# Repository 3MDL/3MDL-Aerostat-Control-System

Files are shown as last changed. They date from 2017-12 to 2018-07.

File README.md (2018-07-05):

# Aerostat Control System #
Remote control system of Tetracam RGB+3 Multispectral camera
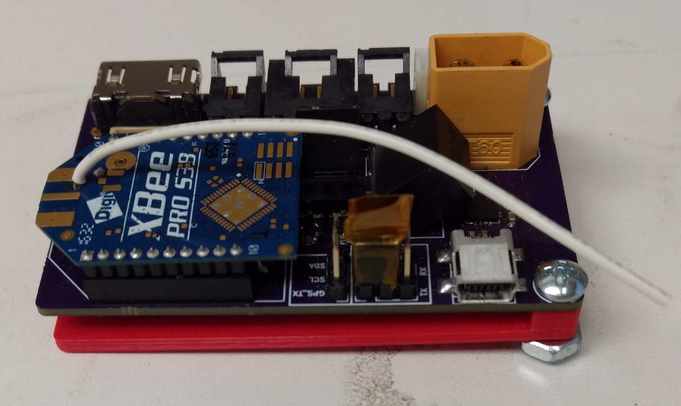
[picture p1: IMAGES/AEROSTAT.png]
image goes here

## Funcions currently implemented ##
- GPS parsing
- Timer based picture taking with settings via EEPROM
- General control over power of attached devices
- RGB+3 diagnostic mode auto-exit

## Functions needed to be implemented ##
- Low battery cuttoff
- Power modes?
- GPS power control on timer like camera

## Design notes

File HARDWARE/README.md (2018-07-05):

# Hardware Docs #

## Load Switch Modules ##
- Utilize the Fairchild FPF2701MX load switch
- Include current shunt resistor and current set resistor

## Voltage Regulator Modules ##
- Stability issues on REV A
- Stability issues on REV B
- Currently using Recom R-78 Module

## Main Board REV C ##
- Redesign that ditches the Pi and instead only uses the ATMega328P
- Uses new Recom R-78 buck regulator module

## Main Board REV D ##
- Fixes numerous pinout issues with REV C
- Passive components moved to bottom side to aid layout
- New connectors are used that utilize side entry to compact the system further

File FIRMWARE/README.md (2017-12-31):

# Firmware Docs #

## Power Test ##
- Simple test that used an Arduino board to monitor the power draw of the RGB+3 camera

## i2c_slave ##
- Arduino sketch of the code that ran on REV A and REV B of the control board
- Includes code that interfaced the Pi with the AVR over I2C

## MAIN ##
- Main code that runs on REV C of the board

## OPTIBOOT FLASH ##
- Avrdude commands and hex file for flashing bootloader onto the ATMega328P without using the Arduino IDE

## PYTHON_PI ##
- Old code from when the project plan included transfering images to the ground using the XBee and Raspberry Pi

## Range Test, RANGE TEST 2, Range Test Desktop ##
- Multiple python scripts and output data from range tests

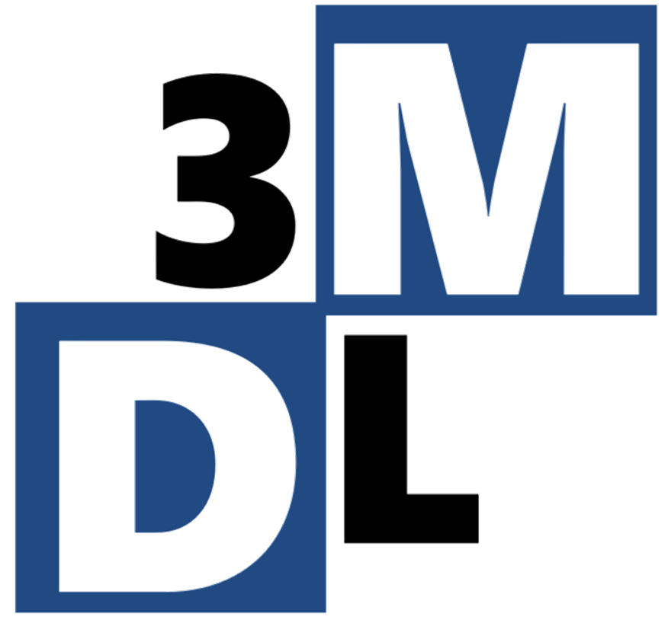
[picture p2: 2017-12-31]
HARDWARE/MOD/3MDL.bmp

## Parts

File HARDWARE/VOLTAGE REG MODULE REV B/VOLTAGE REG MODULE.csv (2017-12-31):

Id | Designator | Package | Quantity | Designation | Supplier and ref
1 | C1,C3 | c_elec_6.3x5.8 | 2 | 10uF
2 | C2 | C_0603 | 1 | 0.1uF
3 | L1 | C_1210 | 1 | 470uH
4 | U1 | QFN-16-1EP_3x3mm_Pitch0.5mm | 1 | TS30011-M050QFNR
5 | T1,T2,T3 | CPAD | 3 | TEST_1P

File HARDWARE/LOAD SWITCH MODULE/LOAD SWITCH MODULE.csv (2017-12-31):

Id | Designator | Package | Quantity | Designation | Supplier and ref
1 | C1,C2 | C_0805 | 2 | 10uF
2 | R1 | R_0805 | 1 | 0.01
3 | R2 | R_0603 | 1 | R
4 | T1,T2,T3,T4 | CPAD | 4 | TEST_1P
5 | U1 | DFN-8-1EP_3x3mm_Pitch0.65mm | 1 | FPF2701MPX

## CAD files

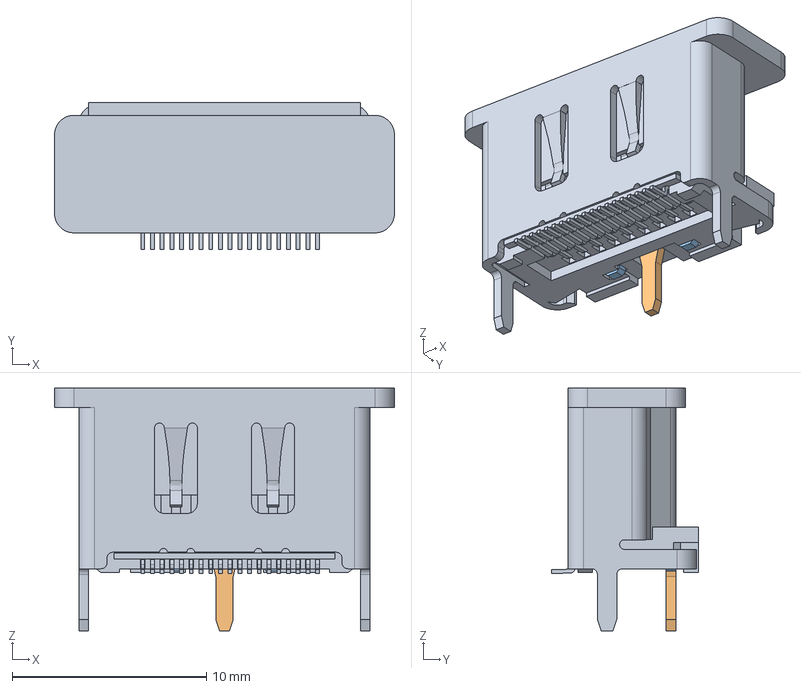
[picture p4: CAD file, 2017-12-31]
HARDWARE/WRL/476591002.stp
17.5 x 7.54 x 12.5 mm

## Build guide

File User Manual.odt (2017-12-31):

Aerostat Control System

User Manual

Table of Contents

About

Hardware Overview

Firmware Overview

Setup

Notices

Hardware Overview

Components Overview

The system consists of <number> parts. This parts include:

The main board itself

<image>

RGB+3 Camera

<image>

FPV Transmitter

<image>

FPV Receiver

<image>

XBee USB Dongle

<image>

Components Description

Main Board

The main board consists of a Printed Circuit Board (PCB) that was designed using KiCAD EDA. PCBs were ordered through OSH Park and hand assembled.

The board is designed to allow wireless control of the Tetracam RGB+3 Camera (discussed in next section). The board includes circuitry and components that utilize an XBee 900MHz Radio Module operating in pass through mode that connects to an ATMega328P (AVR) Microcontroller (MCU). The AVR runs a modified Arduino bootloader that normally runs on the Sparkfun Pro Mini 8MHz model development board. The Optiboot bootloader allows the AVR to be programmed over USB through an FTDI FT230X USB to UART serial bridge. This function is identical to most Arduino boards that do not have native USB functionality on the MCU itself. The AVR also communicates with the on board XBee module over UART serial. Since the AVR only has one hardware UART serial port, on REV C of the board, jumpers wire included to allow selecting between connecting the AVR to the FT230X bridge or the XBee module. This allows the AVR to use hardware UART serial to communicate where it matters. In REV D of the board, a multiplexer (MUX) is used to switch between connecting to the XBee and the FT230X bridge. The control signal for the MUX is the +5VDC line on the USB connector. Therefore as long as the board is plugged into a PC over USB, the board will connect the AVR to the FT230X bridge automatically.

In REV C of the main board, the GP-735T GPS module connected to the AVR using the Arduino Software Serial library. This allows the AVR to know its geographic position. The GPS also connects to the RGB+3 Camera. REV C did not include the necessary UART To RS232 Adapter that the RGB+3 requires. As a result of this, an external adapter was spliced into the system to make due. REV D (in progress) does include the adapter on the board itself to allow for a more compact system. The adapter used is the Maxim Semiconductor MAX3232 which runs off the logic level (+3.3VDC) of the rest of the board but is able of generating the larger voltage swings required for RS232 communication.

Input voltage from USB is +5VDC and is regulated to +3.3VDC using the Recom R-78 buck regulator module (+3.3VDC, 500mA). Previously (REV A & REV B) used a self designed voltage regulator module that utilized the Semtech TS30011 buck regulator. Stability issues on both designs of the regulator module. Both regulators are highly efficient buck regulators. The current Recom R-78 is a through hole module that allows use of a common linear +3.3VDC regulator such as the ST Microelectronics LD1117V33 if the Recom R-78 module is to fail or not work appropriately.

REV C included over voltage protection circuitry using a crowbar type configuration. This was because of the failed design of the voltage regulator modules. The crowbar circuits were arranged on the input 3 Cell 11.1V Lithium Polymer Battery (3S LIPO) into the board and the output of the 3.3V regulator module. On REV C, the crowbar circuits were tested to be working but since the triacs in the circuit were removable, the circuits were ran without the crowbars operation for some time. No ill effects were observed so for the sake of simplicity, the crowbar circuits were removed in REV D.

Please refer to the schematics for further information on the main board.

RGB+3 Camera

The Tetracam RGB+3 Camera is a multi spectral camera designed for use on aircraft. The camera interfaces with the main board over a standard HDMI cable. This cable can further be referred to as the Multi-GPO (General Purpose Input Output) cable. Tetracam set forth standard connections for the system. Most of these connections are standard inputs or outputs at a +3.3VDC logic level with the exception of the RS232 port that connects to the GPS. Additionally, the camera includes NTSC video over the HDMI connector as well. Beware, the HDMI does not have a standard HDMI pinout! Connecting the camera to another device over the HDMI cable is not recommended! The main board mentioned above includes the necessary connections to an First Person View (FPV) transmitter and GPS module with RS232 level shifter. The RS323 port is accessible additionally through a 3.5mm auxiallaty jack on the camera. The NTSC video stream is accessible additionally through an RCA plug on the camera.

Tetracam supplied a key shaped PCB that has a HDMI connector on one end and breakouts the different signals of the HDMI cable.

Please refer to the RGB+3 User Guide from Tetracam for more information on the camera.

FPV Transmitter

For simplicity’s sake, an external FPV transmitter was utilized, the FPV transmitter model number is the TS832 module. This module supports multiple different modules and is interfaced via a 5 pin connector.

FPV Receiver

The matching receiver for the chosen transmitter is the one included in this project. The chosen receiver’s model number is the RC832 module. This module also supports the same channels as the FPV transmitter. Normally, the FPV receiver outputs video onto an RCA type plug but this receiver was modified to include a USB video capture card. This means that the receiver can be directly plugged into a PC over USB type A in which the device acts as a standard web cam. The device is also powered over the +5VDC from the USB cable. On Debian Linux, the camera is recognized however on Windows, drivers may need to be installed. In this case, the drivers required are the USBTV007 driver.

XBee USB Dongle

The XBee USB dongle from Sparkfun allows a simple connection between the XBee and the PC. The XBees chosen are the XBee Pro 900 model with wire whip antenna. These have been tested to about 1000ft successfully. Currently the XBees are configured to run at 9600 Baud. To interface with the XBee, a COM port program needs to be installed on the host PC. For Windows, a suitable program is PuTTY. On Linux, a suitable program is CuteCom. Command processing on the main board expects to NOT see line end characters, therefore set the line ending to NONE in both programs to reliably communicate with the main board.

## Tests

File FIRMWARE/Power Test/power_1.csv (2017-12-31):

Data
0
0
0
0
0
0
0
0
0
0
0
0
0
0
0
0
0
0
0
0
0
0
0
0
0
0
0
0
0
0
0
0
0
0
0
0
0
0
0
0
0
0
0
0
0
0
0
0
0
0
0
0
0
0
0
0
0
0
0
0
0
0
0
0
0
0
0
0
0
0
0
0
0
0
0
0
0
0
0
0
0
0
0
0
0
0
0
0
0
0
0
0
0
0
0
0
0
0
0
0
0
0
0
0
0
0
0
0
0
0
0
0
0
0
0
0
0
0
0
0
0
0
0
0
0
0
0
0
0
0
0
0
0
0
0
0
0
0
0
0
0
0
0
0
0
0
0
0
0
0
0
0
0
0
0
0
0
0
0
0
0
0
0
0
0
0
0
0
0
0
0
0
0
0
0
0
0
0
0
0
0
0
0
0
0
0
0
0
0
0
0
0
0
0
0
0
0
0
0
0
0
0
0
0
0
0
0
0
0
0
0
0
0
0
0
0
0
0
0
0
0
0
0
0
0
0
0
0
0
0
0
0
0
0
0
0
0
0
0
0
0
0
0
0
0
0
0
0
0
0
0
0
0
0
0
0
0
0
0
0
0
0
0
0
0
0
0
0
0
0
0
0
0
0
0
0
0
0
0
0
0
0
0
0
0
0
0
0
0
0
0
0
0
0
0
0
0
0
0
0
0
0
0
0
0
0
0
0
0
0
0
0
0
0
0
0
0
0
0
0
0
0
0
0
0
0
0
0
0
0
0
0
0
0
0
0
0
0
0
0
0
0
0
0
0
0
0
0
0
0
0
0
0
0
0
0
0
0
0
0
0
0
0
0
0
0
0
0
0
0
0
0
0
0
0
0
0
0
0
0
0
0
0
0
0
0
0
0
0
0
0
0
0
0
0
0
0
0
0
0
0
0
0
0
0
0
0
0
0
0
0
0
0
0
0
0
0
0
0
0
0
0
0
0
0
0
0
0
0
0
0
0
0
0
0
0
0
0
0
0
0
0
0
0
0
0
0
0
0
0
0
0
0
0
0
0
0
0
0
0
0
0
0
0
0
0
0
0
0
0
0
0
0
0
0
0
0
0
0
0
0
0
0
0
0
0
0
0
0
0
0
0
0
0
0
0
0
0
0
0
0
0
0
0
0
0
0
0
0
0
0
0
0
0
0
0
0
0
0
0
0
0
0
0
0
0
0
0
0
0
0
0
0
0
0
0
0
0
0
0
0
0
0
0
0
0
0
0
0
0
0
0
0
0
0
0
0
0
0
0
0
0
0
0
0
0
0
0
0
0
0
0
0
0
0
0
0
0
0
0
0
0
0
0
0
0
0
0
0
0
0
0
0
0
0
0
0
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

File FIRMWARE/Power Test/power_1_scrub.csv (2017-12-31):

Data
0
0
0
0
0
0
0
0
0
0
0
0
0
0
0
0
0
0
0
0
0
0
0
0
0
0
0
0
0
0
0
0
0
0
0
0
0
0
0
0
0
0
0
0
0
0
0
0
0
0
0
0
0
0
0
0
0
0
0
0
0
0
0
0
0
0
0
0
0
0
0
0
0
0
0
0
0
0
0
0
0
0
0
0
0
0
0
0
0
0
0
0
0
0
0
0
0
0
0
0
0
0
0
0
0
0
0
0
0
0
0
0
0
0
0
0
0
0
0
0
0
0
0
0
0
0
0
0
0
0
0
0
0
0
0
0
0
0
0
0
0
0
0
0
0
0
0
0
0
0
0
0
0
0
0
0
0
0
0
0
0
0
0
0
0
0
0
0
0
0
0
0
0
0
0
0
0
0
0
0
0
0
0
0
0
0
0
0
0
0
0
0
0
0
0
0
0
0
0
0
0
0
0
0
0
0
0
0
0
0
0
0
0
0
0
0
0
0
0
0
0
0
0
0
0
0
0
0
0
0
0
0
0
0
0
0
0
0
0
0
0
0
0
0
0
0
0
0
0
0
0
0
0
0
0
0
0
0
0
0
0
0
0
0
0
0
0
0
0
0
0
0
0
0
0
0
0
0
0
0
0
0
0
0
0
0
0
0
0
0
0
0
0
0
0
0
0
0
0
0
0
0
0
0
0
0
0
0
0
0
0
0
0
0
0
0
0
0
0
0
0
0
0
0
0
0
0
0
0
0
0
0
0
0
0
0
0
0
0
0
0
0
0
0
0
0
0
0
0
0
0
0
0
0
0
0
0
0
0
0
0
0
0
0
0
0
0
0
0
0
0
0
0
0
0
0
0
0
0
0
0
0
0
0
0
0
0
0
0
0
0
0
0
0
0
0
0
0
0
0
0
0
0
0
0
0
0
0
0
0
0
0
0
0
0
0
0
0
0
0
0
0
0
0
0
0
0
0
0
0
0
0
0
0
0
0
0
0
0
0
0
0
0
0
0
0
0
0
0
0
0
0
0
0
0
0
0
0
0
0
0
0
0
0
0
0
0
0
0
0
0
0
0
0
0
0
0
0
0
0
0
0
0
0
0
0
0
0
0
0
0
0
0
0
0
0
0
0
0
0
0
0
0
0
0
0
0
0
0
0
0
0
0
0
0
0
0
0
0
0
0
0
0
0
0
0
0
0
0
0
0
0
0
0
0
0
0
0
0
0
0
0
0
0
0
0
0
0
0
0
0
0
0
0
0
0
0
0
0
0
0
0
0
0
0
0
0
0
0
0
0
0
0
0
0
0
0
0
0
0
0
0
0
0
0
0
0
0
0
0
0
0
0
0
0
0
0
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

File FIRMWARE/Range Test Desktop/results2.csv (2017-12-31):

no-lock
no-lock
no-lock
no-lock
no-lock
no-lock
no-lock
no-lock
no-lock
no-lock
no-lock
no-lock
no-lock
no-lock
no-lock
no-lock
no-lock
no-lock
no-lock
no-lock
no-lock
no-lock
no-lock
no-lock
no-lock
no-lock
no-lock
no-lock
no-lock
no-lock
no-lock
no-lock
no-lock
no-lock
no-lock
4139.58539 | 08336.84105
4139.59691 | 08336.84269
4139.62988 | 08336.84835
4139.65172 | 08336.85186
4139.65697 | 08336.85220
4139.66180 | 08336.85274
4139.66313 | 08336.85223
4139.66588 | 08336.85027
4139.66550 | 08336.84961
4139.66550 | 08336.84904
4139.66570 | 08336.84843
4139.66600 | 08336.84787
4139.66645 | 08336.84713
4139.66664 | 08336.84655
4139.66722 | 08336.84577
4139.66751 | 08336.84500
4139.66821 | 08336.84431
4139.66854 | 08336.84356
4139.66852 | 08336.84288
4139.66885 | 08336.84221
4139.66968 | 08336.84159
4139.66987 | 08336.84098
4139.67000 | 08336.84022
4139.67027 | 08336.83956
4139.67068 | 08336.83891
4139.67160 | 08336.83819
4139.67235 | 08336.83702
4139.67193 | 08336.83643
4139.67276 | 08336.83587
4139.67310 | 08336.83524
4139.67380 | 08336.83478
4139.68069 | 08336.81947
4139.68095 | 08336.81860
4139.68054 | 08336.81756
4139.67994 | 08336.81642
4139.67989 | 08336.81599
no-lock
no-lock
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

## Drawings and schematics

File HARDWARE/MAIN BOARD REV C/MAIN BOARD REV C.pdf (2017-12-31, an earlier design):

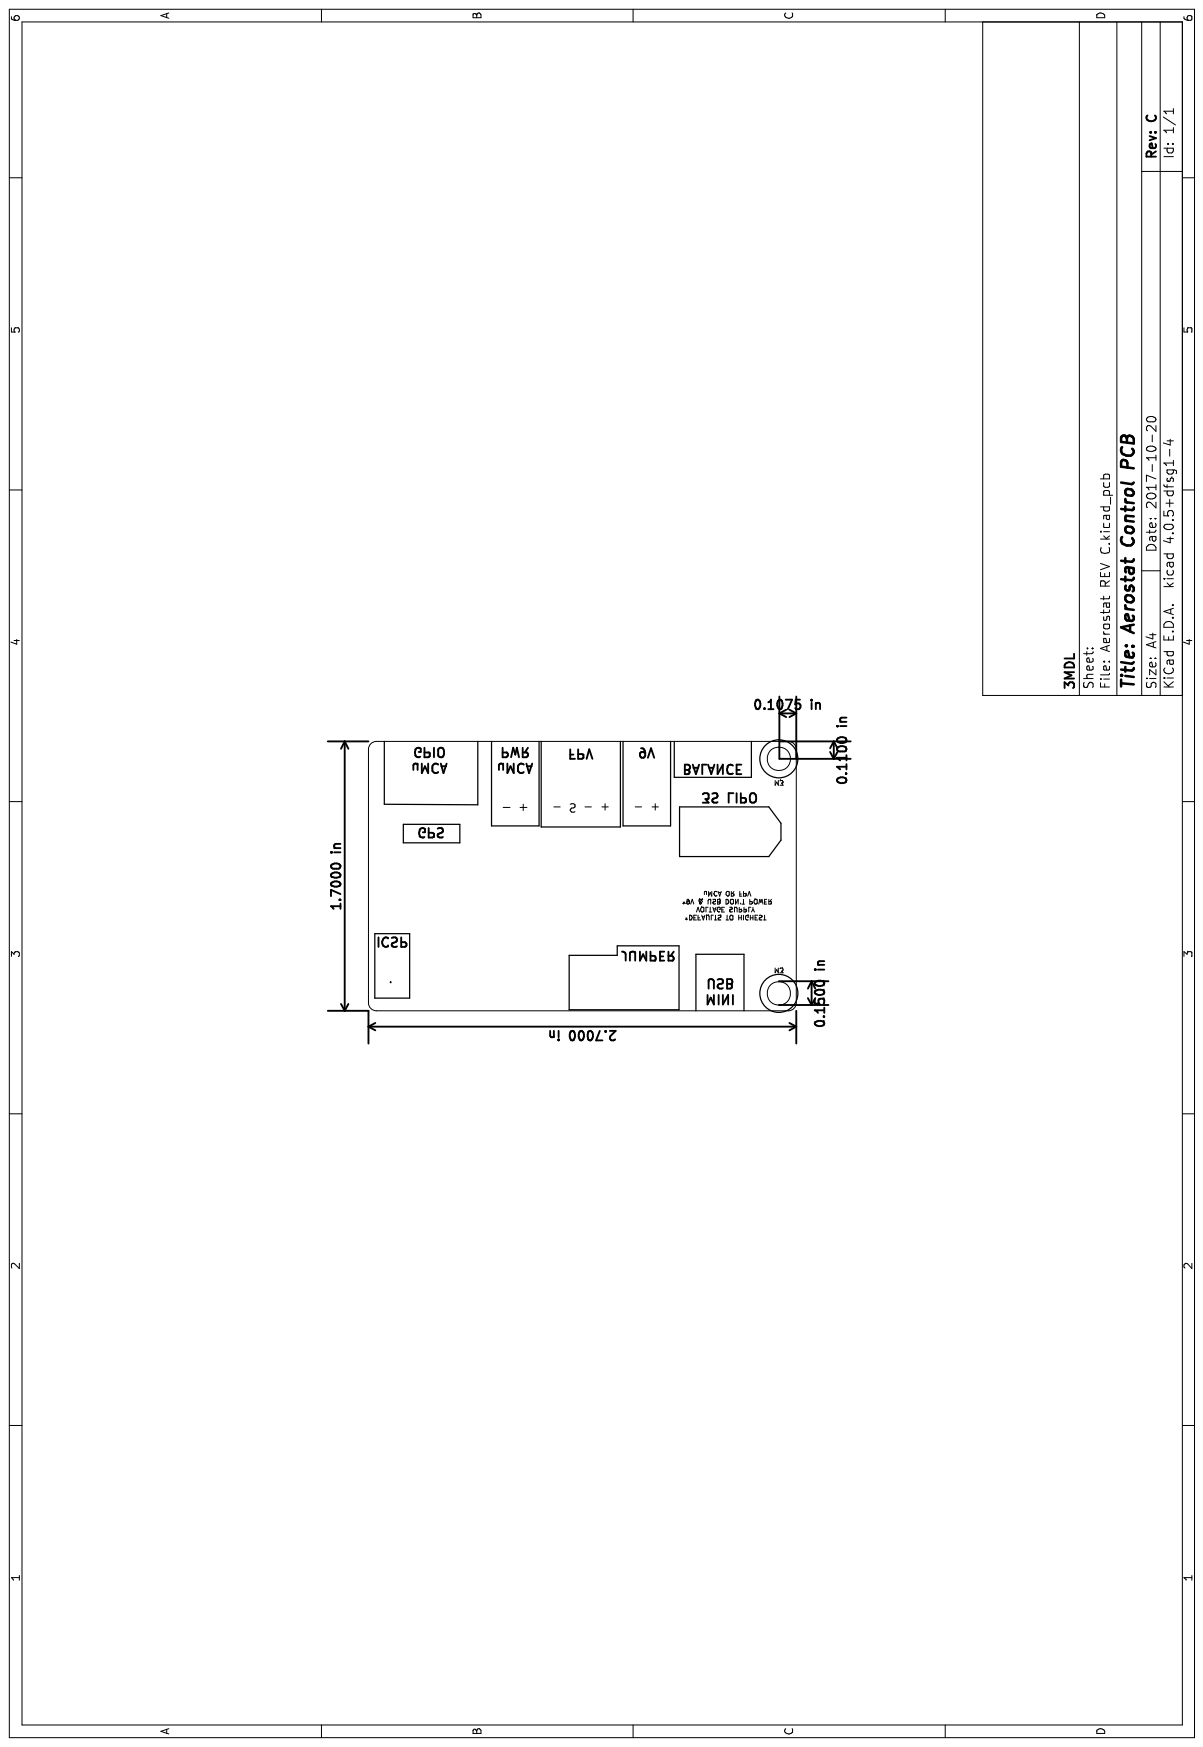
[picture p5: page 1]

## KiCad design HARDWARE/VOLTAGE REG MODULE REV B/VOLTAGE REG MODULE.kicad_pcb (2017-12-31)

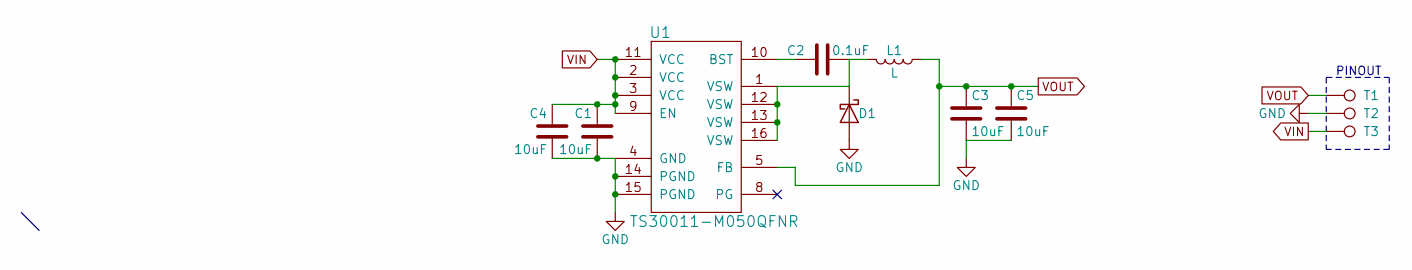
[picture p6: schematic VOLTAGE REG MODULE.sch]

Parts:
C1, C3, C4, C5: 10uF; C_0805
C2: 0.1uF; C_0603
D1: D_Schottky; SOD-123
L1: L; C_1210
T1, T2, T3: TEST_1P; CPAD
U1: TS30011-M050QFNR; QFN-16-1EP_3x3mm_Pitch0.5mm

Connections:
GND: C1.2, C3.2, C4.2, C5.2, D1.2 (A), T2.1, U1.4 (GND), U1.14 (PGND), U1.15 (PGND), U1.17
unnamed: C2.1, D1.1 (K), L1.2, U1.1 (VSW), U1.12 (VSW), U1.13 (VSW), U1.16 (VSW)
unnamed: C2.2, U1.10 (BST)
VIN: C1.1, C4.1, T3.1, U1.2 (VCC), U1.3 (VCC), U1.9 (EN), U1.11 (VCC)
VOUT: C3.1, C5.1, L1.1, T1.1, U1.5 (FB)

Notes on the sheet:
PINOUT

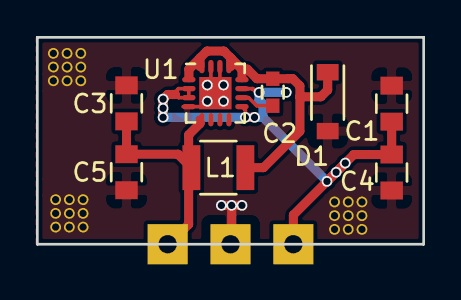
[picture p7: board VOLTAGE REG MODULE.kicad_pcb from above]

Board: 2 copper layers, 21.5 x 11.5 mm, 11 parts (0 on the bottom side), 5 nets.

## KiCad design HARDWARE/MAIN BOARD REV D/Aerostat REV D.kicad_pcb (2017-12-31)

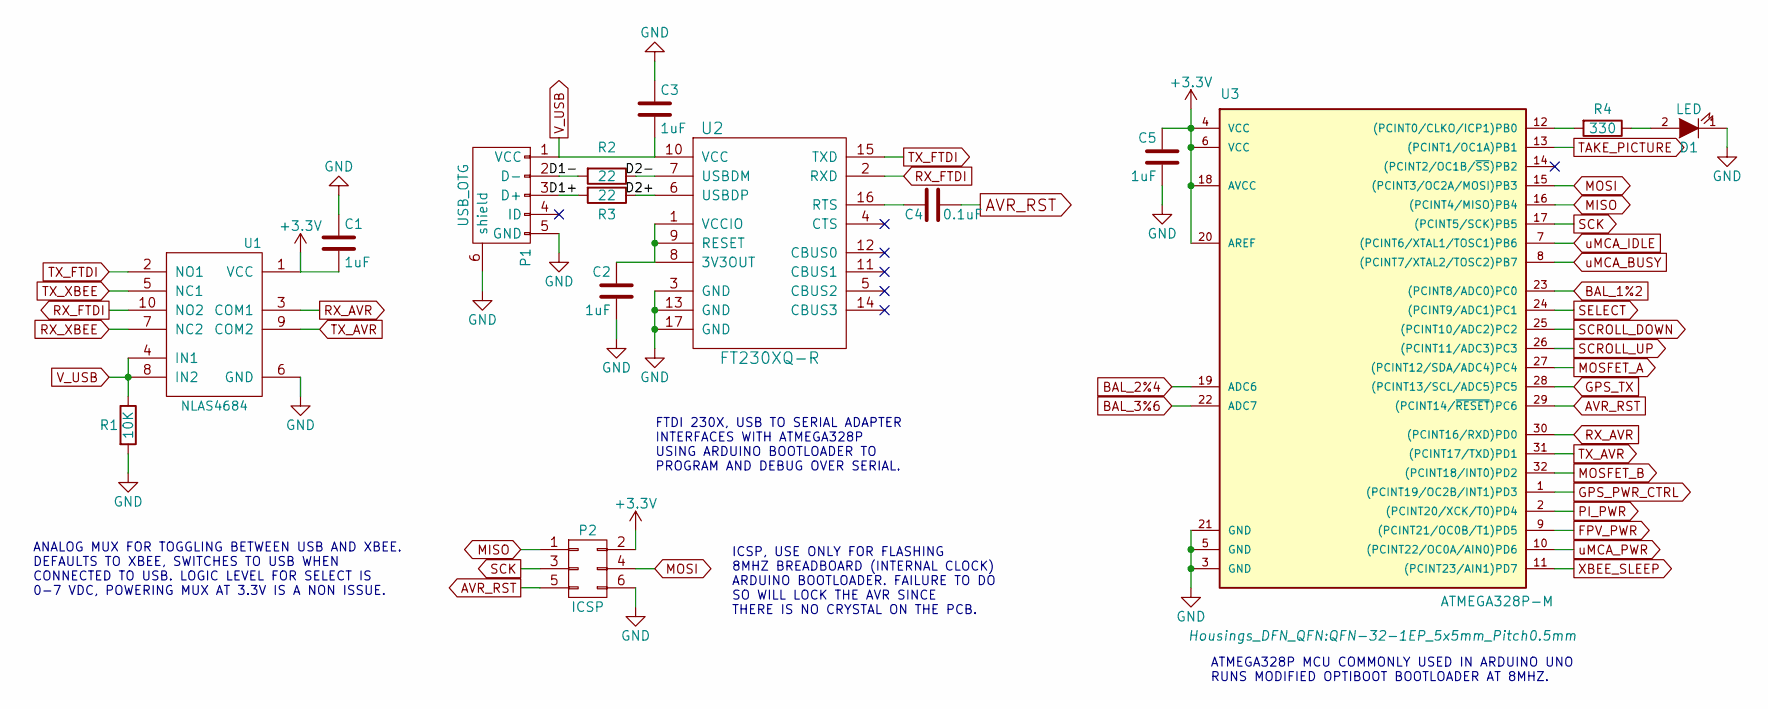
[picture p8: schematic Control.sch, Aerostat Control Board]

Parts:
C1, C2, C3, C5: 1uF; C_0603
C4: 0.1uF; C_0603
D1: LED; LED_0603
P1: USB_OTG; UX60-MB-5ST
P2: ICSP; 2.54 ICSP
R1: 10K; R_0603
R2, R3: 22; R_0603
R4: 330; R_0603
U1: NLAS4684; DFN-10-1EP_3x3mm_Pitch0.5mm
U2: FT230XQ-R; QFN-16-1EP_4x4mm_Pitch0.65mm
U3: ATMEGA328P-M; QFN-32-1EP_5x5mm_Pitch0.5mm

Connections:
+3V3: C1.2, C5.1, P2.2, U1.1 (VCC), U3.4 (VCC), U3.6 (VCC), U3.18 (AVCC), U3.20 (AREF); also elsewhere on the board
/Control/D1+: P1.3 (D+), R3.2
/Control/D1-: P1.2 (D-), R2.2
/Control/D2+: R3.1, U2.6 (USBDP)
/Control/D2-: R2.1, U2.7 (USBDM)
AVR_RST: C4.1, P2.5, U3.29 ((PCINT14/~RESET~)PC6)
BAL_1%2: U3.23 ((PCINT8/ADC0)PC0); also elsewhere on the board
BAL_2%4: U3.19 (ADC6); also elsewhere on the board
BAL_3%6: U3.22 (ADC7); also elsewhere on the board
FPV_PWR: U3.9 ((PCINT21/OC0B/T1)PD5); also elsewhere on the board
GND: C1.1, C2.2, C3.1, C5.2, D1.1 (K), P1.5 (GND), P1.6 (shield), P2.6, R1.2, U1.6 (GND), U2.3 (GND), U2.13 (GND), U2.17 (GND), U3.3 (GND), U3.5 (GND), U3.21 (GND); also elsewhere on the board
GPS_PWR_CTRL: U3.1 ((PCINT19/OC2B/INT1)PD3); also elsewhere on the board
GPS_TX: U3.28 ((PCINT13/SCL/ADC5)PC5); also elsewhere on the board
MISO: P2.1, U3.16 ((PCINT4/MISO)PB4)
MOSFET_A: U3.27 ((PCINT12/SDA/ADC4)PC4); also elsewhere on the board
MOSFET_B: U3.32 ((PCINT18/INT0)PD2); also elsewhere on the board
MOSI: P2.4, U3.15 ((PCINT3/OC2A/MOSI)PB3)
unnamed: C2.1, U2.1 (VCCIO), U2.8 (3V3OUT), U2.9 (RESET)
unnamed: C4.2, U2.16 (RTS)
unnamed: D1.2 (A), R4.1
unnamed: R4.2, U3.12 ((PCINT0/CLKO/ICP1)PB0)
PI_PWR: U3.2 ((PCINT20/XCK/T0)PD4)
RX_AVR: U1.3 (COM1), U3.30 ((PCINT16/RXD)PD0)
RX_FTDI: U1.10 (NO2), U2.2 (RXD)
RX_XBEE: U1.7 (NC2); also elsewhere on the board
SCK: P2.3, U3.17 ((PCINT5/SCK)PB5)
SCROLL_DOWN: U3.25 ((PCINT10/ADC2)PC2); also elsewhere on the board
SCROLL_UP: U3.26 ((PCINT11/ADC3)PC3); also elsewhere on the board
SELECT: U3.24 ((PCINT9/ADC1)PC1); also elsewhere on the board
TAKE_PICTURE: U3.13 ((PCINT1/OC1A)PB1); also elsewhere on the board
TX_AVR: U1.9 (COM2), U3.31 ((PCINT17/TXD)PD1)
TX_FTDI: U1.2 (NO1), U2.15 (TXD)
TX_XBEE: U1.5 (NC1); also elsewhere on the board
V_USB: C3.2, P1.1 (VCC), R1.1, U1.4 (IN1), U1.8 (IN2), U2.10 (VCC); also elsewhere on the board
XBEE_SLEEP: U3.11 ((PCINT23/AIN1)PD7); also elsewhere on the board
uMCA_BUSY: U3.8 ((PCINT7/XTAL2/TOSC2)PB7); also elsewhere on the board
uMCA_IDLE: U3.7 ((PCINT6/XTAL1/TOSC1)PB6); also elsewhere on the board
uMCA_PWR: U3.10 ((PCINT22/OC0A/AIN0)PD6); also elsewhere on the board

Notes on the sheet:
ICSP, USE ONLY FOR FLASHING 8MHZ BREADBOARD (INTERNAL CLOCK) ARDUINO BOOTLOADER. FAILURE TO DO SO WILL LOCK THE AVR SINCE THERE IS NO CRYSTAL ON THE PCB.
FTDI 230X, USB TO SERIAL ADAPTER INTERFACES WITH ATMEGA328P USING ARDUINO BOOTLOADER TO PROGRAM AND DEBUG OVER SERIAL.
ATMEGA328P MCU COMMONLY USED IN ARDUINO UNO RUNS MODIFIED OPTIBOOT BOOTLOADER AT 8MHZ.
ANALOG MUX FOR TOGGLING BETWEEN USB AND XBEE. DEFAULTS TO XBEE, SWITCHES TO USB WHEN CONNECTED TO USB. LOGIC LEVEL FOR SELECT IS 0-7 VDC, POWERING MUX AT 3.3V IS A NON ISSUE.

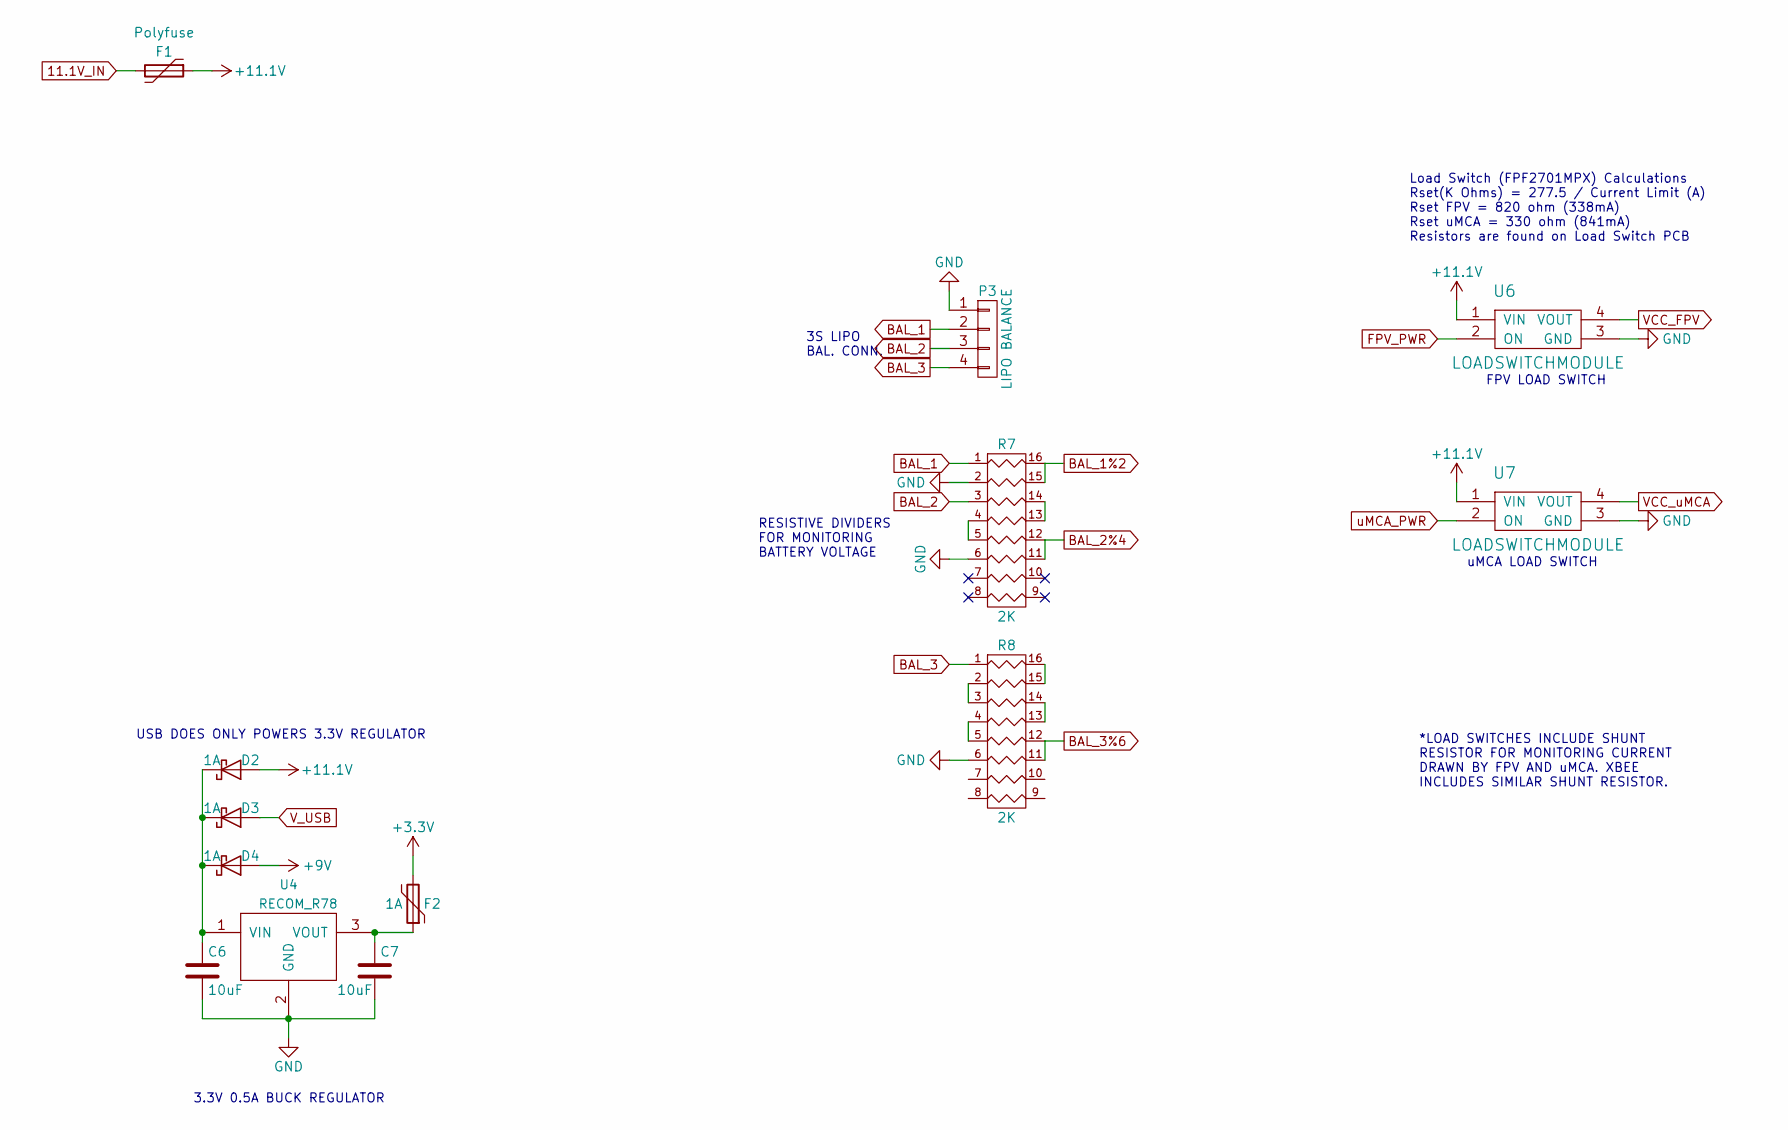
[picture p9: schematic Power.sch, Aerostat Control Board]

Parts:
C6, C7: 10uF; C_0603
D2, D3, D4: 1A; D_SOD-123
F1: Polyfuse; C_1210
F2: 1A; C_1210
P3: LIPO BALANCE; JST_B4B-XH-A(LF)(SN)
R7, R8: 2K; R_Array_Convex_8x0602
U4: RECOM_R78; R-78E
U6, U7: LOADSWITCHMODULE; LOAD SWITCH MODULE

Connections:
11.1V_IN: F1.2; also elsewhere on the board
+3V3: F2.2; also elsewhere on the board
+9V: D4.2 (A); also elsewhere on the board
+12C: D2.2 (A), F1.1, U6.1 (VIN), U7.1 (VIN)
BAL_1: P3.2, R7.1
BAL_1%2: R7.15 (R2), R7.16 (R1); also elsewhere on the board
BAL_2: P3.3, R7.3
BAL_2%4: R7.11 (R6), R7.12 (R5); also elsewhere on the board
BAL_3: P3.4, R8.1
BAL_3%6: R8.11 (R6), R8.12 (R5); also elsewhere on the board
FPV_PWR: U6.2 (ON); also elsewhere on the board
GND: C6.2, C7.2, P3.1, R7.2, R7.6, R8.6, U4.2 (GND), U6.3 (GND), U7.3 (GND); also elsewhere on the board
unnamed: C6.1, D2.1 (K), D3.1 (K), D4.1 (K), U4.1 (VIN)
unnamed: C7.1, F2.1, U4.3 (VOUT)
unnamed: R7.4, R7.5
unnamed: R7.13 (R4), R7.14 (R3)
unnamed: R8.2, R8.3
unnamed: R8.4, R8.5
unnamed: R8.13 (R4), R8.14 (R3)
unnamed: R8.15 (R2), R8.16 (R1)
VCC_FPV: U6.4 (VOUT); also elsewhere on the board
VCC_uMCA: U7.4 (VOUT); also elsewhere on the board
V_USB: D3.2 (A); also elsewhere on the board
uMCA_PWR: U7.2 (ON); also elsewhere on the board

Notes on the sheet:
3S LIPO BAL. CONN.
RESISTIVE DIVIDERS FOR MONITORING BATTERY VOLTAGE
FPV LOAD SWITCH
uMCA LOAD SWITCH
*LOAD SWITCHES INCLUDE SHUNT RESISTOR FOR MONITORING CURRENT DRAWN BY FPV AND uMCA. XBEE INCLUDES SIMILAR SHUNT RESISTOR.
Load Switch (FPF2701MPX) Calculations Rset(K Ohms) = 277.5 / Current Limit (A) Rset FPV = 820 ohm (338mA) Rset uMCA = 330 ohm (841mA) Resistors are found on Load Switch PCB
3.3V 0.5A BUCK REGULATOR
USB DOES ONLY POWERS 3.3V REGULATOR

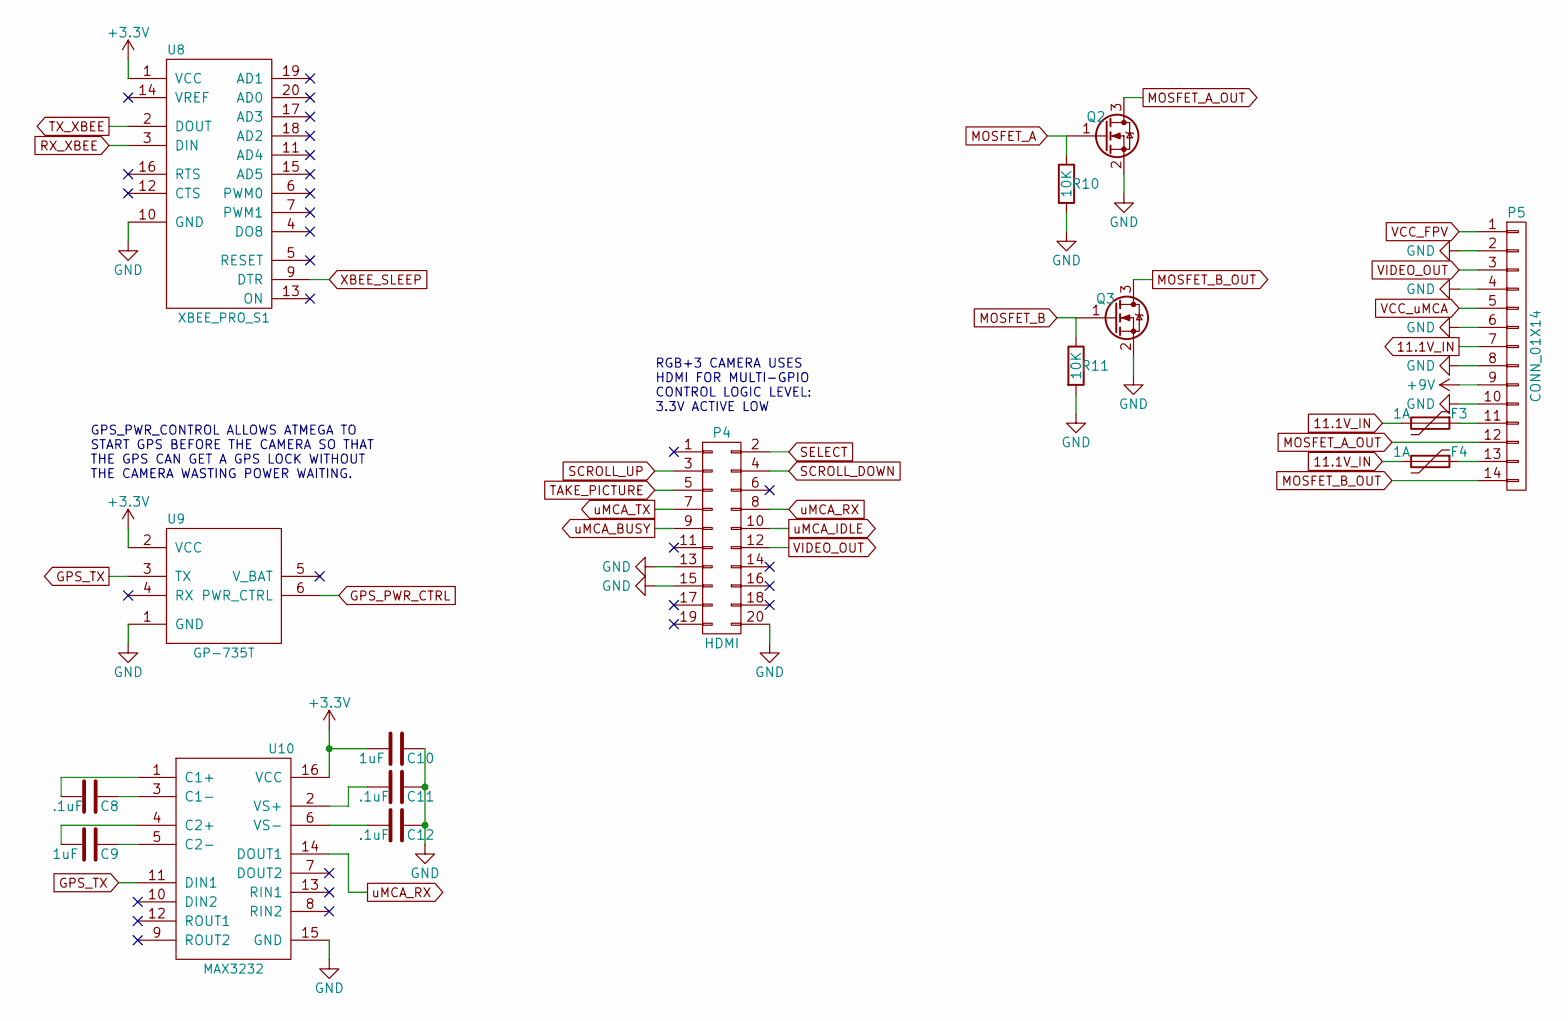
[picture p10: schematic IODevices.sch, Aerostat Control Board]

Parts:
C8, C11, C12: .1uF; C_0603
C9, C10: 1uF; C_0603
F3, F4: 1A; C_1210
P4: HDMI; 10029449-111RLF
P5: CONN_01X14; TE1X14
Q2, Q3: Q_NMOS_GSD; SOT-23
R10, R11: 10K; R_0603
U8: XBEE_PRO_S1; DIP-20
U9: GP-735T
U10: MAX3232; TSSOP-16_4.4x5mm_Pitch0.65mm

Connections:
11.1V_IN: F3.2, F4.2, P5.7; also elsewhere on the board
+3V3: C10.2, U8.1 (VCC), U9.2 (VCC), U10.16 (VCC); also elsewhere on the board
+9V: P5.9; also elsewhere on the board
GND: C10.1, C11.1, C12.1, P4.13, P4.15, P4.20, P5.2, P5.4, P5.6, P5.8, P5.10, Q2.2 (S), Q3.2 (S), R10.2, R11.2, U8.10 (GND), U9.1 (GND), U10.15 (GND); also elsewhere on the board
GPS_PWR_CTRL: U9.6 (PWR_CTRL); also elsewhere on the board
GPS_TX: U9.3 (TX), U10.11 (DIN1); also elsewhere on the board
MOSFET_A: Q2.1 (G), R10.1; also elsewhere on the board
MOSFET_A_OUT: P5.12, Q2.3 (D)
MOSFET_B: Q3.1 (G), R11.1; also elsewhere on the board
MOSFET_B_OUT: P5.14, Q3.3 (D)
unnamed: C8.1, U10.3 (C1-)
unnamed: C8.2, U10.1 (C1+)
unnamed: C9.1, U10.5 (C2-)
unnamed: C9.2, U10.4 (C2+)
unnamed: C11.2, U10.2 (VS+)
unnamed: C12.2, U10.6 (VS-)
unnamed: F3.1, P5.11
unnamed: F4.1, P5.13
RX_XBEE: U8.3 (DIN); also elsewhere on the board
SCROLL_DOWN: P4.4; also elsewhere on the board
SCROLL_UP: P4.3; also elsewhere on the board
SELECT: P4.2; also elsewhere on the board
TAKE_PICTURE: P4.5; also elsewhere on the board
TX_XBEE: U8.2 (DOUT); also elsewhere on the board
VCC_FPV: P5.1; also elsewhere on the board
VCC_uMCA: P5.5; also elsewhere on the board
VIDEO_OUT: P4.12, P5.3
XBEE_SLEEP: U8.9 (DTR); also elsewhere on the board
uMCA_BUSY: P4.9; also elsewhere on the board
uMCA_IDLE: P4.10; also elsewhere on the board
uMCA_RX: P4.8, U10.14 (DOUT1)
uMCA_TX: P4.7

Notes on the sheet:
GPS_PWR_CONTROL ALLOWS ATMEGA TO START GPS BEFORE THE CAMERA SO THAT THE GPS CAN GET A GPS LOCK WITHOUT THE CAMERA WASTING POWER WAITING.
RGB+3 CAMERA USES HDMI FOR MULTI-GPIO CONTROL LOGIC LEVEL: 3.3V ACTIVE LOW

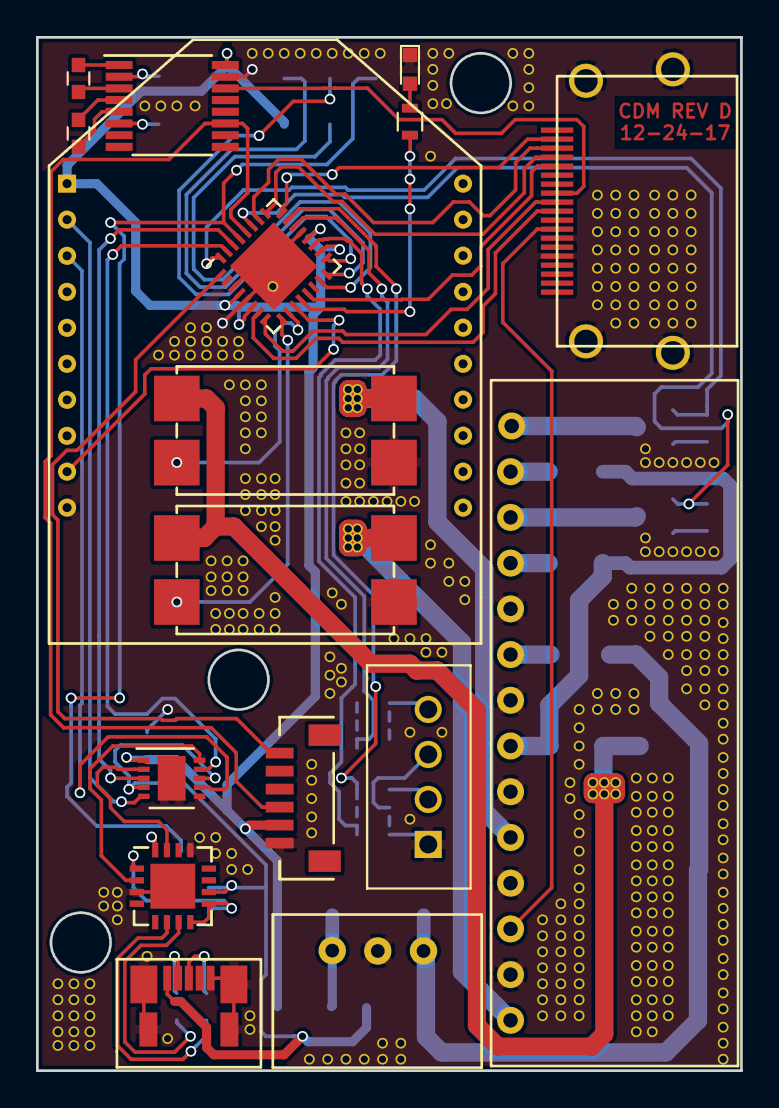
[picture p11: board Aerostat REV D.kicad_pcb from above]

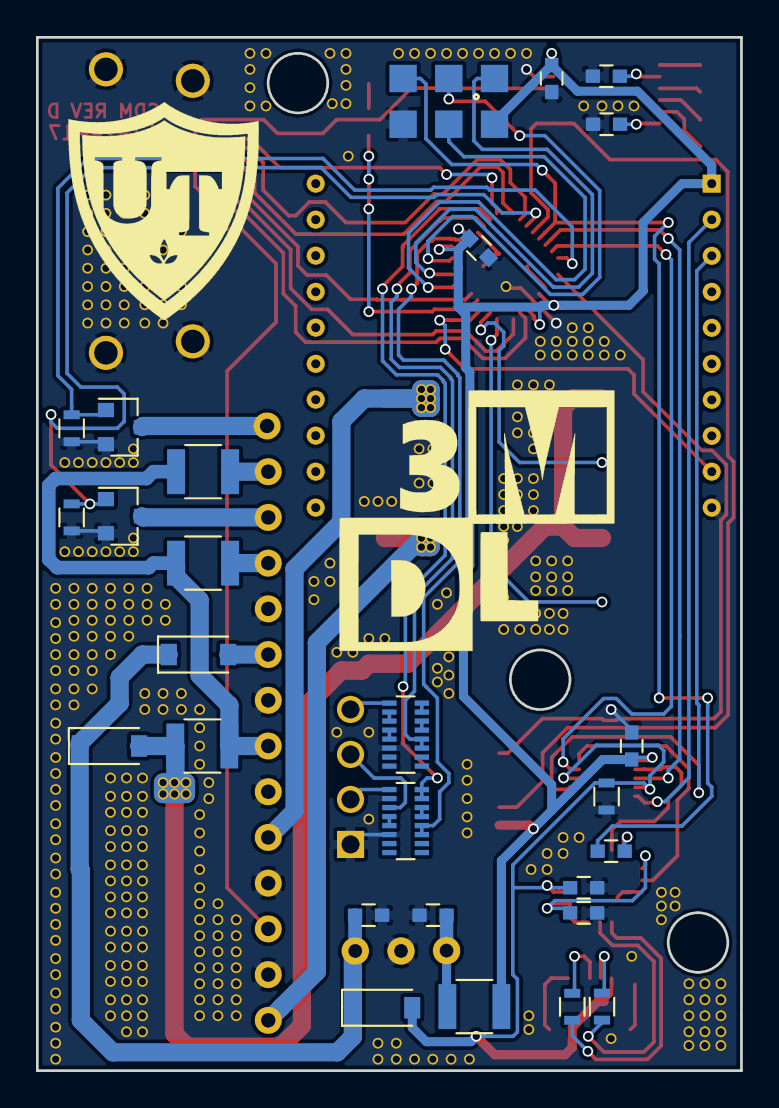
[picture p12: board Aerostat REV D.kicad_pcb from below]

Board: 2 copper layers, 39.1 x 57.4 mm, 44 parts (27 on the bottom side), 65 nets.

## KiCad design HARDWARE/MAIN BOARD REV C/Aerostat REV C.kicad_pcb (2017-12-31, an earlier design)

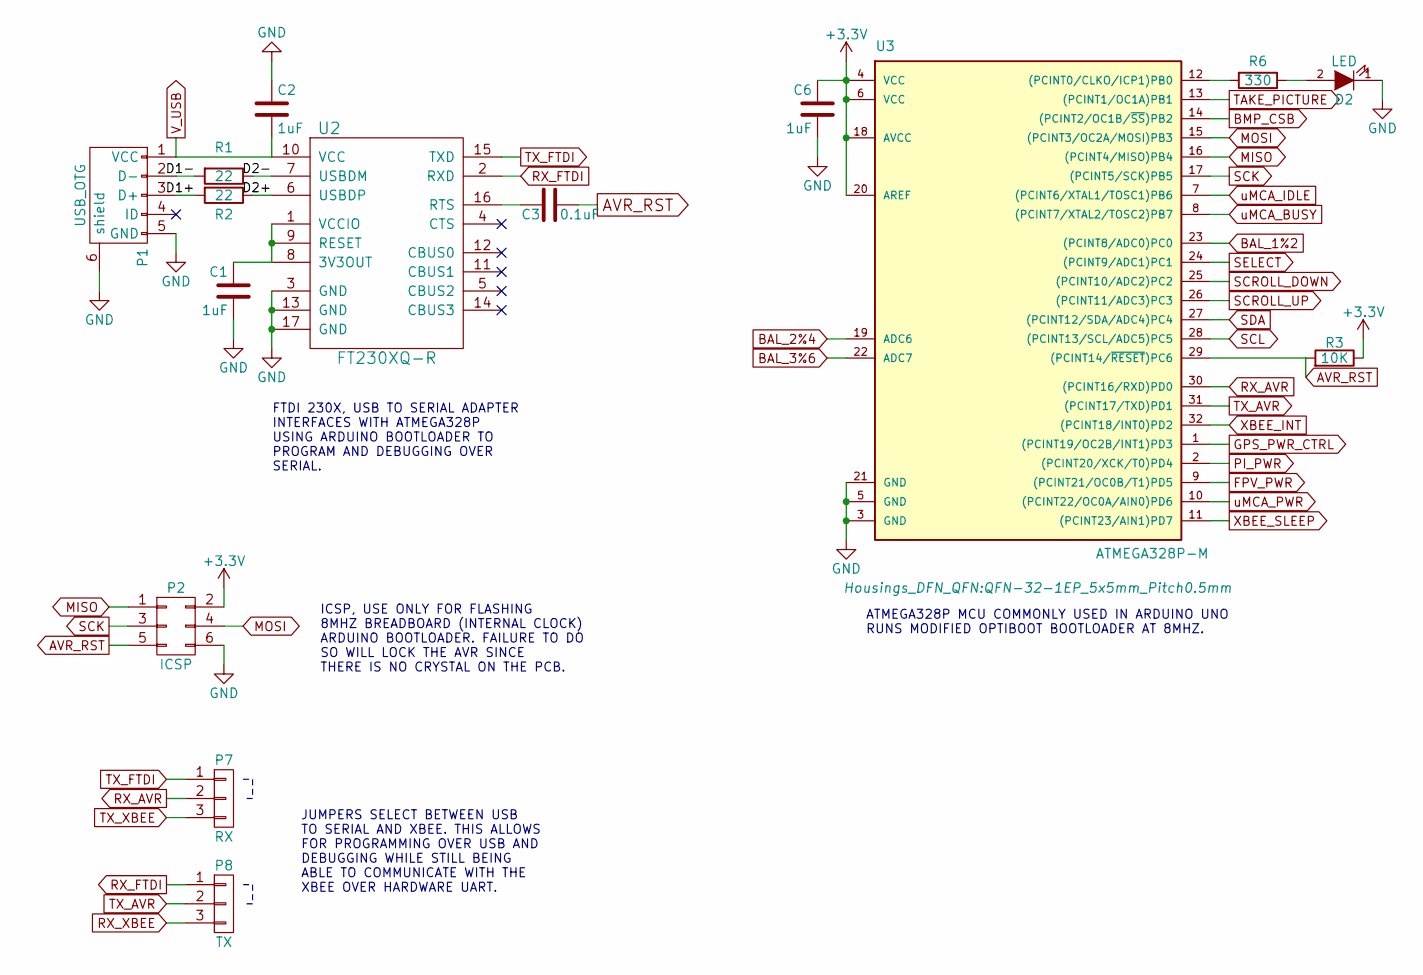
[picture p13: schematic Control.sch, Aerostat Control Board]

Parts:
C1, C2, C6: 1uF; C_0603
C3: 0.1uF; C_0603
D2: LED; LED_0603
P1: USB_OTG; UX60-MB-5ST
P2: ICSP; 2.54 ICSP
P7: RX; Pin_Header_Straight_1x03_Pitch2.54mm
P8: TX; Pin_Header_Straight_1x03_Pitch2.54mm
R1, R2: 22; R_0603
R3: 10K; R_0603
R6: 330; R_0603
U2: FT230XQ-R; QFN-16-1EP_4x4mm_Pitch0.65mm
U3: ATMEGA328P-M; QFN-32-1EP_5x5mm_Pitch0.5mm

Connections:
+3V3: C6.1, P2.2, R3.1, U3.4 (VCC), U3.6 (VCC), U3.18 (AVCC), U3.20 (AREF); also elsewhere on the board
/Control/D1+: P1.3 (D+), R2.2
/Control/D1-: P1.2 (D-), R1.2
/Control/D2+: R2.1, U2.6 (USBDP)
/Control/D2-: R1.1, U2.7 (USBDM)
AVR_RST: C3.1, P2.5, R3.2, U3.29 ((PCINT14/~RESET~)PC6)
BAL_1%2: U3.23 ((PCINT8/ADC0)PC0); also elsewhere on the board
BAL_2%4: U3.19 (ADC6); also elsewhere on the board
BAL_3%6: U3.22 (ADC7); also elsewhere on the board
BMP_CSB: U3.14 ((PCINT2/OC1B/~SS~)PB2); also elsewhere on the board
FPV_PWR: U3.9 ((PCINT21/OC0B/T1)PD5); also elsewhere on the board
GND: C1.2, C2.1, C6.2, D2.1 (K), P1.5 (GND), P1.6 (shield), P2.6, U2.3 (GND), U2.13 (GND), U2.17 (GND), U3.3 (GND), U3.5 (GND), U3.21 (GND), U3.33; also elsewhere on the board
GPS_PWR_CTRL: U3.1 ((PCINT19/OC2B/INT1)PD3); also elsewhere on the board
MISO: P2.1, U3.16 ((PCINT4/MISO)PB4); also elsewhere on the board
MOSI: P2.4, U3.15 ((PCINT3/OC2A/MOSI)PB3); also elsewhere on the board
unnamed: C1.1, U2.1 (VCCIO), U2.8 (3V3OUT), U2.9 (RESET)
unnamed: C3.2, U2.16 (RTS)
unnamed: D2.2 (A), R6.1
unnamed: R6.2, U3.12 ((PCINT0/CLKO/ICP1)PB0)
PI_PWR: U3.2 ((PCINT20/XCK/T0)PD4)
RX_AVR: P7.2, U3.30 ((PCINT16/RXD)PD0)
RX_FTDI: P8.1, U2.2 (RXD)
RX_XBEE: P8.3; also elsewhere on the board
SCK: P2.3, U3.17 ((PCINT5/SCK)PB5); also elsewhere on the board
SCL: U3.28 ((PCINT13/SCL/ADC5)PC5); also elsewhere on the board
SCROLL_DOWN: U3.25 ((PCINT10/ADC2)PC2); also elsewhere on the board
SCROLL_UP: U3.26 ((PCINT11/ADC3)PC3); also elsewhere on the board
SDA: U3.27 ((PCINT12/SDA/ADC4)PC4); also elsewhere on the board
SELECT: U3.24 ((PCINT9/ADC1)PC1); also elsewhere on the board
TAKE_PICTURE: U3.13 ((PCINT1/OC1A)PB1); also elsewhere on the board
TX_AVR: P8.2, U3.31 ((PCINT17/TXD)PD1)
TX_FTDI: P7.1, U2.15 (TXD)
TX_XBEE: P7.3; also elsewhere on the board
V_USB: C2.2, P1.1 (VCC), U2.10 (VCC); also elsewhere on the board
XBEE_INT: U3.32 ((PCINT18/INT0)PD2); also elsewhere on the board
XBEE_SLEEP: U3.11 ((PCINT23/AIN1)PD7); also elsewhere on the board
uMCA_BUSY: U3.8 ((PCINT7/XTAL2/TOSC2)PB7); also elsewhere on the board
uMCA_IDLE: U3.7 ((PCINT6/XTAL1/TOSC1)PB6); also elsewhere on the board
uMCA_PWR: U3.10 ((PCINT22/OC0A/AIN0)PD6); also elsewhere on the board

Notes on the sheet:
JUMPERS SELECT BETWEEN USB TO SERIAL AND XBEE. THIS ALLOWS FOR PROGRAMMING OVER USB AND DEBUGGING WHILE STILL BEING ABLE TO COMMUNICATE WITH THE XBEE OVER HARDWARE UART.
ICSP, USE ONLY FOR FLASHING 8MHZ BREADBOARD (INTERNAL CLOCK) ARDUINO BOOTLOADER. FAILURE TO DO SO WILL LOCK THE AVR SINCE THERE IS NO CRYSTAL ON THE PCB.
FTDI 230X, USB TO SERIAL ADAPTER INTERFACES WITH ATMEGA328P USING ARDUINO BOOTLOADER TO PROGRAM AND DEBUGGING OVER SERIAL.
ATMEGA328P MCU COMMONLY USED IN ARDUINO UNO RUNS MODIFIED OPTIBOOT BOOTLOADER AT 8MHZ.

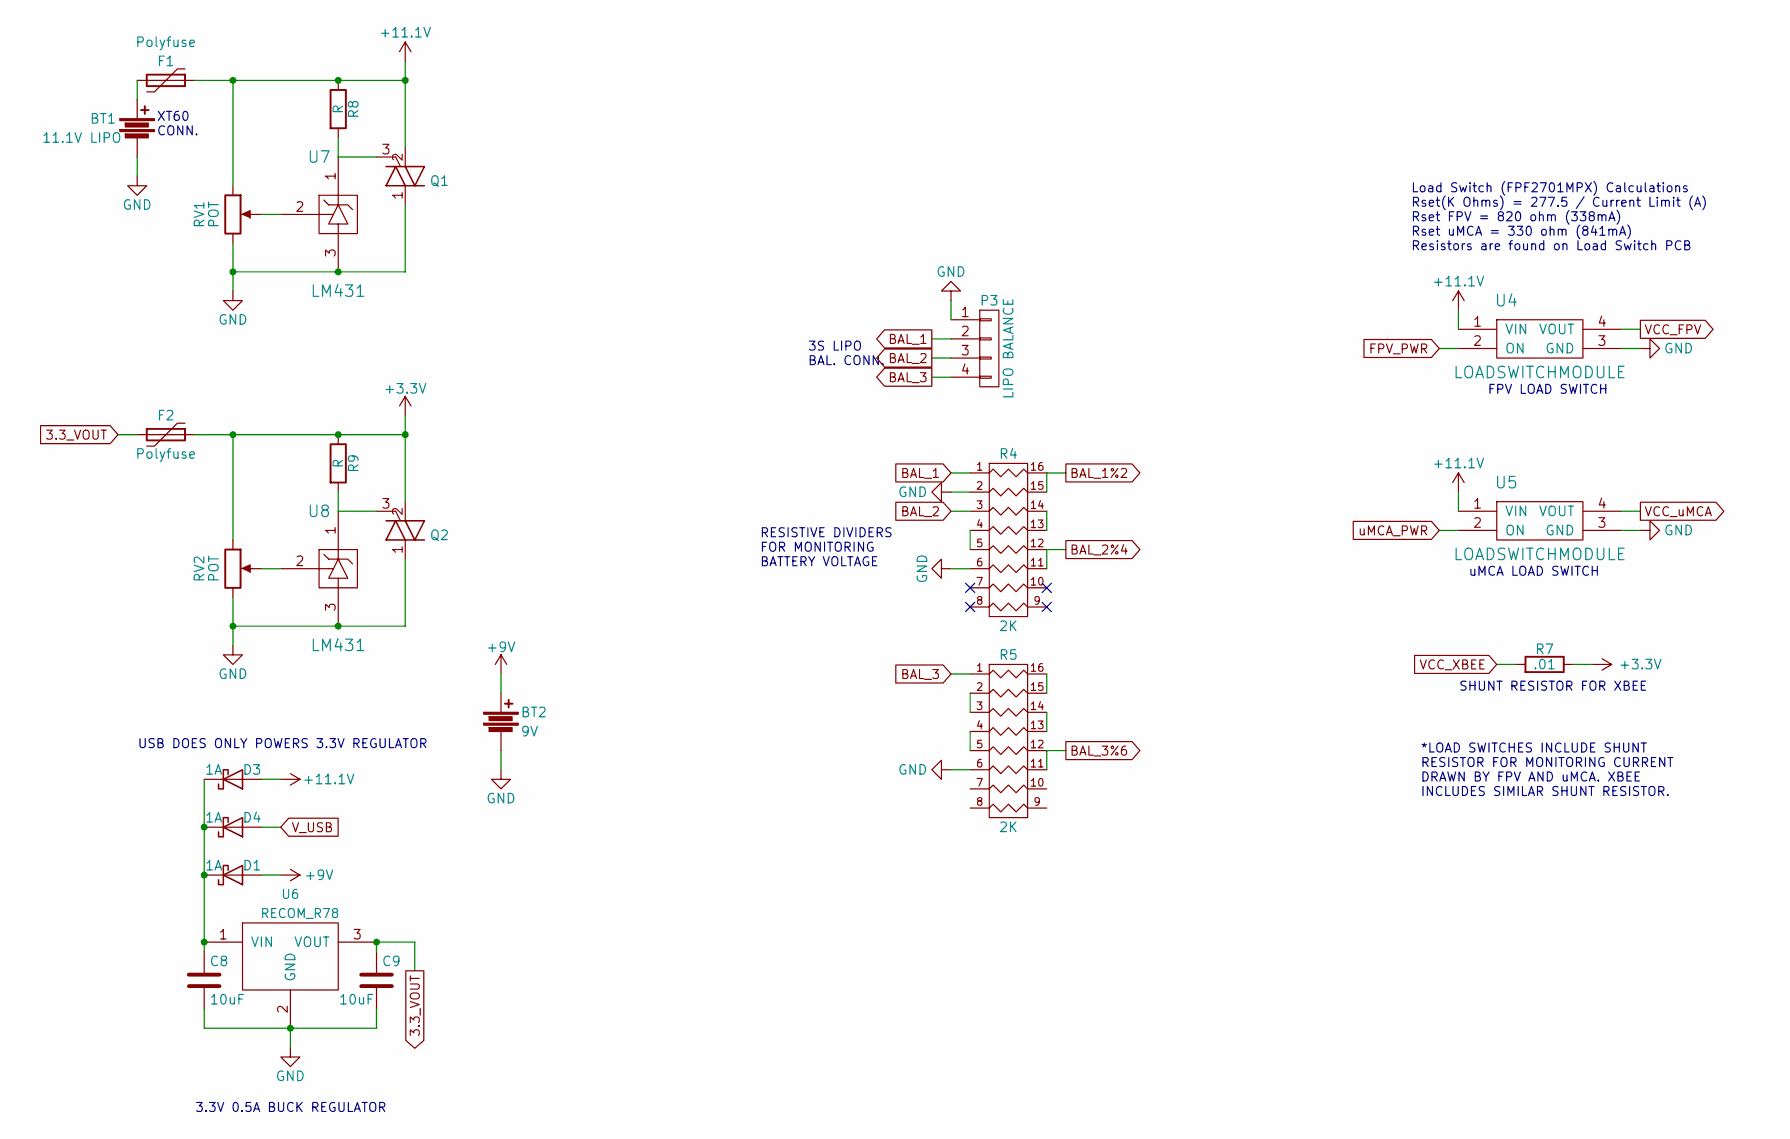
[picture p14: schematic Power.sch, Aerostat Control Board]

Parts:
BT1: 11.1V LIPO; XT60
BT2: 9V; TE1X2
C8, C9: 10uF; C_0603
D1, D3, D4: 1A; D_SOD-123
F1, F2: Polyfuse; C_1210
P3: LIPO BALANCE; JST_B4B-XH-A(LF)(SN)
Q1, Q2: Q_TRIAC_AAG; Pin_Header_Straight_1x03_Pitch2.54mm
R4, R5: 2K; R_Array_Convex_8x0602
R7: .01; R_0805
R8, R9: R; R_0603
RV1, RV2: POT; Potentiometer_Trimmer-EVM3E
U4, U5: LOADSWITCHMODULE; LOAD SWITCH MODULE
U6: RECOM_R78; R-78E
U7, U8: LM431; SOT-323_SC-70

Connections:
3.3_VOUT: C9.1, F2.2, U6.3 (VOUT)
+3V3: F2.1, Q2.2 (A2), R7.1, R9.1, RV2.1; also elsewhere on the board
+9V: BT2.1, D1.2 (A)
+12C: D3.2 (A), F1.1, Q1.2 (A2), R8.1, RV1.1, U4.1 (VIN), U5.1 (VIN)
BAL_1: P3.2, R4.1
BAL_1%2: R4.15 (R2), R4.16 (R1); also elsewhere on the board
BAL_2: P3.3, R4.3
BAL_2%4: R4.11 (R6), R4.12 (R5); also elsewhere on the board
BAL_3: P3.4, R5.1
BAL_3%6: R5.11 (R6), R5.12 (R5); also elsewhere on the board
FPV_PWR: U4.2 (ON); also elsewhere on the board
GND: BT1.2, BT2.2, C8.2, C9.2, P3.1, Q1.1 (A1), Q2.1 (A1), R4.2, R4.6, R5.6, RV1.3, RV2.3, U4.3 (GND), U5.3 (GND), U6.2 (GND), U7.3, U8.3; also elsewhere on the board
unnamed: BT1.1, F1.2
unnamed: C8.1, D1.1 (K), D3.1 (K), D4.1 (K), U6.1 (VIN)
unnamed: Q1.3 (G), R8.2, U7.1
unnamed: Q2.3 (G), R9.2, U8.1
unnamed: R4.4, R4.5
unnamed: R4.13 (R4), R4.14 (R3)
unnamed: R5.2, R5.3
unnamed: R5.4, R5.5
unnamed: R5.13 (R4), R5.14 (R3)
unnamed: R5.15 (R2), R5.16 (R1)
unnamed: RV1.2, U7.2
unnamed: RV2.2, U8.2
VCC_FPV: U4.4 (VOUT); also elsewhere on the board
VCC_XBEE: R7.2; also elsewhere on the board
VCC_uMCA: U5.4 (VOUT); also elsewhere on the board
V_USB: D4.2 (A); also elsewhere on the board
uMCA_PWR: U5.2 (ON); also elsewhere on the board

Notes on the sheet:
XT60 CONN.
3S LIPO BAL. CONN.
RESISTIVE DIVIDERS FOR MONITORING BATTERY VOLTAGE
FPV LOAD SWITCH
uMCA LOAD SWITCH
SHUNT RESISTOR FOR XBEE
*LOAD SWITCHES INCLUDE SHUNT RESISTOR FOR MONITORING CURRENT DRAWN BY FPV AND uMCA. XBEE INCLUDES SIMILAR SHUNT RESISTOR.
Load Switch (FPF2701MPX) Calculations Rset(K Ohms) = 277.5 / Current Limit (A) Rset FPV = 820 ohm (338mA) Rset uMCA = 330 ohm (841mA) Resistors are found on Load Switch PCB
3.3V 0.5A BUCK REGULATOR
USB DOES ONLY POWERS 3.3V REGULATOR

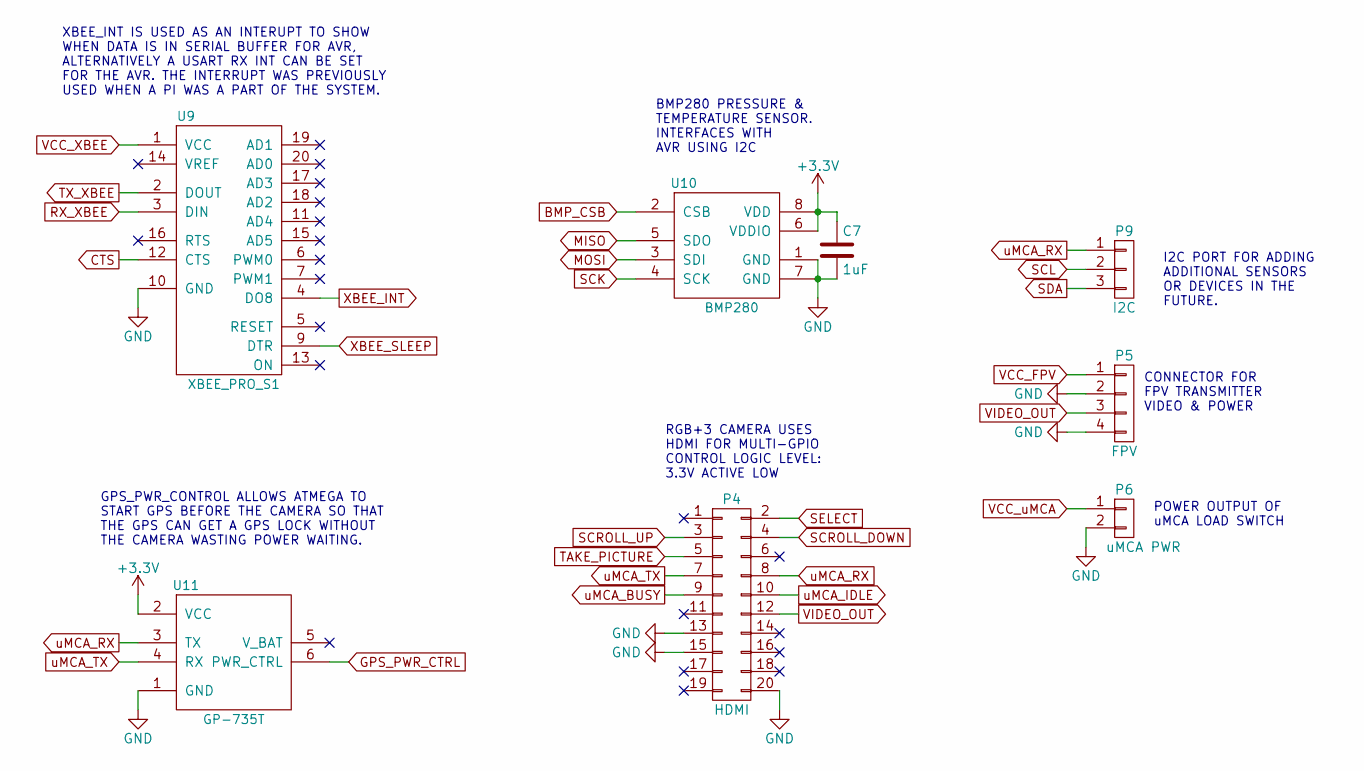
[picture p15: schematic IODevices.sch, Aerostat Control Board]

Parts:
C7: 1uF; C_0603
P4: HDMI; 10029449-111RLF
P5: FPV; TE1X4
P6: uMCA PWR; TE1X2
P9: I2C; Pin_Header_Straight_1x03_Pitch2.54mm
U9: XBEE_PRO_S1; DIP-20
U10: BMP280; LGA-8
U11: GP-735T

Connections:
+3V3: C7.1, U10.6 (VDDIO), U10.8 (VDD), U11.2 (VCC); also elsewhere on the board
BMP_CSB: U10.2 (CSB); also elsewhere on the board
CTS: U9.12 (CTS)
GND: C7.2, P4.13, P4.15, P4.20, P5.2, P5.4, P6.2, U9.10 (GND), U10.1 (GND), U10.7 (GND), U11.1 (GND), U11.7; also elsewhere on the board
GPS_PWR_CTRL: U11.6 (PWR_CTRL); also elsewhere on the board
MISO: U10.5 (SDO); also elsewhere on the board
MOSI: U10.3 (SDI); also elsewhere on the board
RX_XBEE: U9.3 (DIN); also elsewhere on the board
SCK: U10.4 (SCK); also elsewhere on the board
SCL: P9.2; also elsewhere on the board
SCROLL_DOWN: P4.4; also elsewhere on the board
SCROLL_UP: P4.3; also elsewhere on the board
SDA: P9.3; also elsewhere on the board
SELECT: P4.2; also elsewhere on the board
TAKE_PICTURE: P4.5; also elsewhere on the board
TX_XBEE: U9.2 (DOUT); also elsewhere on the board
VCC_FPV: P5.1; also elsewhere on the board
VCC_XBEE: U9.1 (VCC); also elsewhere on the board
VCC_uMCA: P6.1; also elsewhere on the board
VIDEO_OUT: P4.12, P5.3
XBEE_INT: U9.4 (DO8); also elsewhere on the board
XBEE_SLEEP: U9.9 (DTR); also elsewhere on the board
uMCA_BUSY: P4.9; also elsewhere on the board
uMCA_IDLE: P4.10; also elsewhere on the board
uMCA_RX: P4.8, P9.1, U11.3 (TX)
uMCA_TX: P4.7, U11.4 (RX)

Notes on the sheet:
GPS_PWR_CONTROL ALLOWS ATMEGA TO START GPS BEFORE THE CAMERA SO THAT THE GPS CAN GET A GPS LOCK WITHOUT THE CAMERA WASTING POWER WAITING.
XBEE_INT IS USED AS AN INTERUPT TO SHOW WHEN DATA IS IN SERIAL BUFFER FOR AVR, ALTERNATIVELY A USART RX INT CAN BE SET FOR THE AVR. THE INTERRUPT WAS PREVIOUSLY USED WHEN A PI WAS A PART OF THE SYSTEM.
POWER OUTPUT OF uMCA LOAD SWITCH
CONNECTOR FOR FPV TRANSMITTER VIDEO & POWER
RGB+3 CAMERA USES HDMI FOR MULTI-GPIO CONTROL LOGIC LEVEL: 3.3V ACTIVE LOW
BMP280 PRESSURE & TEMPERATURE SENSOR. INTERFACES WITH AVR USING I2C
I2C PORT FOR ADDING ADDITIONAL SENSORS OR DEVICES IN THE FUTURE.

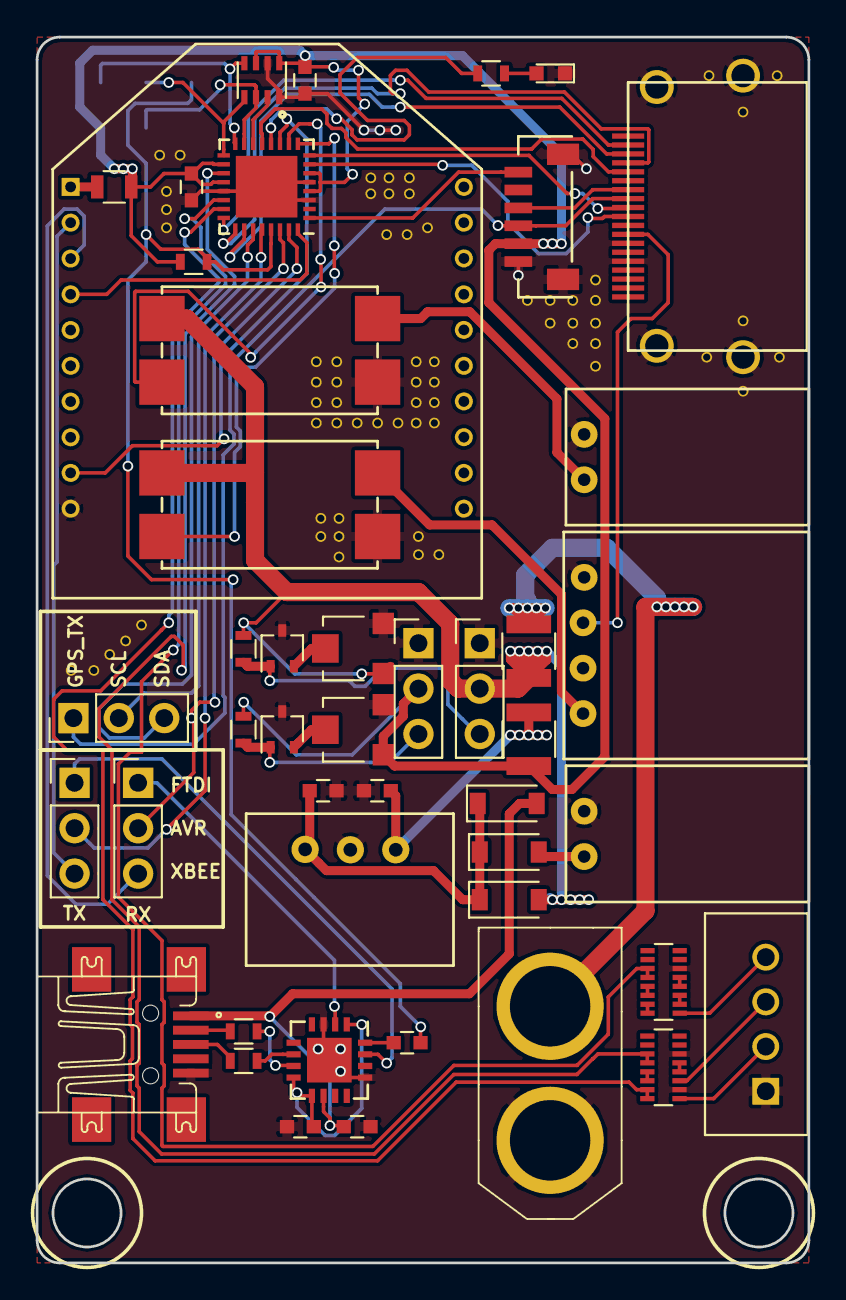
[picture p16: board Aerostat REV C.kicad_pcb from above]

Board: 2 copper layers, 43.2 x 68.6 mm, 47 parts (1 on the bottom side), 62 nets.

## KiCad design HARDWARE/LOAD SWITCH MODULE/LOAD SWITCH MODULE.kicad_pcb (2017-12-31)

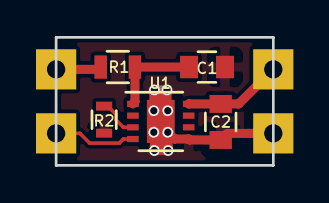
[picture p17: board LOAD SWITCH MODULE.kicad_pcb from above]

Board: 2 copper layers, 12.1 x 7.1 mm, 9 parts (0 on the bottom side), 6 nets.

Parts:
C1, C2: 10uF; C_0805
R1: 0.01; R_0805
R2: R; R_0603
T1, T2, T3, T4: TEST_1P; CPAD
U1: FPF2701MPX; DFN-8-1EP_3x3mm_Pitch0.65mm

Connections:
GND: C1.2, C2.1, R2.2, T4.1, U1.5, U1.9
unnamed: C1.1, R1.1, U1.1
unnamed: R2.1, U1.3
ON: T3.1, U1.4
VIN: R1.2, T1.1
VOUT: C2.2, T2.1, U1.8

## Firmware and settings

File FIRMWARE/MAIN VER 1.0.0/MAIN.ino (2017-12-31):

//Arduino Pro Mini Pin Map
#define PD1 1
#define PD0 0
#define PD2 2
#define PD3 3
#define PD4 4
#define PD5 5
#define PD6 6
#define PD7 7
#define PB0 8
#define PB1 9
#define PC3 17
#define PC2 16
#define PC1 15
#define PB4 12
#define PB3 11
#define PB2 10
#define PC4 A4
#define PC5 A5
//A7 and A6 already used in Port Names directly

//AVR Port Names
#define TAKE_PICTURE PB1
#define BMP_CSB 10 //PB2
#define SELECT PC1
#define SCROLL_DOWN PC2
#define SCROLL_UP PC3
#define XBEE_INT PD2
#define GPS_PWR_CTRL PD3
#define PI_PWR PD4
#define FPV_PWR PD5
#define uMCA_PWR PD6
#define XBEE_SLEEP PD7
#define BAL_1 PC0
#define BAL_2 A6
#define BAL_3 A7
#define LED PB0
#define SDA PC4
#define SCL PC5

#define uMCA_IDLE PB6 //not used in pin map
#define uMCA_BUSY PB7 //not used in pin map

#define startMsgLen 6
#define endMsgLen 2
#define gpsBufferSize 600
#define startMsg "$GPGLL"
#define endMsg 0x0D
#define gpsDelay 500UL
bool transmitGps = false;
bool parseGps = true;
bool gpsDirect = false;
int bufferIndex = 0;
char gpsBuffer[gpsBufferSize] = {}; //"circular" buffer for incoming gps data << not actually circular at this point, instead the buffer is made larger than needed
unsigned long gpsTimer = 0;

unsigned long uMCATimer = 0;
unsigned long uMCASleep;
unsigned long uMCADelay;
int uMCAPics;
bool uMCASleepFlag = false;
int uMCACurrentPic = 0;

#include <EEPROM.h>
#include "SoftwareSerial.h"
SoftwareSerial gpsSerial(SCL, SDA);

int readBusy() {
  if (PINB & (1 << uMCA_BUSY)) {
    return 1;
  } else {
    return 0;
  }
}

int readIdle() { //more reliable than readBusy() because red led for busy flashes
  if (PINB & (1 << uMCA_IDLE)) {
    return 1;
  } else {
    return 0;
  }
}

void takePic() {
  if (readIdle() == 0) {
    Serial.println("CAMERA BUSY");
    return 0;
  } else {
    Serial.println("RUNNING");
    digitalWrite(TAKE_PICTURE, HIGH);
    delay(100);
    digitalWrite(TAKE_PICTURE, LOW);
    delay(200);
    for (int i = 0; i < 1000 && readIdle() == 0; i ++) {
      if (i == 999) {
        Serial.println("IDLE TIMEOUT");
      }
      delay(10);
    }
  }
  Serial.println("DONE");
}

void updateParam() {
  int dataRead;
  dataRead = EEPROM.read(0);
  dataRead = EEPROM.read(1) + dataRead * 10;
  uMCASleep = dataRead;
  dataRead = EEPROM.read(2);
  dataRead = EEPROM.read(3) + dataRead * 10;
  uMCADelay = dataRead;
  dataRead = EEPROM.read(4);
  dataRead = EEPROM.read(5) + dataRead * 10;
  uMCAPics = dataRead;
}


void setup() {
  Serial.begin(9600); //needs to be same as XBee and Serial Monitor
  gpsSerial.begin(9600);
  gpsSerial.listen();

  pinMode(FPV_PWR, OUTPUT);
  pinMode(uMCA_PWR, OUTPUT);
  pinMode(TAKE_PICTURE, OUTPUT);
  pinMode(SELECT, OUTPUT);
  pinMode(GPS_PWR_CTRL, OUTPUT);
  pinMode(XBEE_SLEEP, OUTPUT);
  pinMode(LED, OUTPUT);

  digitalWrite(XBEE_SLEEP, LOW); //turn on XBEE
  digitalWrite(GPS_PWR_CTRL, LOW); //turn GPS off
  digitalWrite(FPV_PWR, HIGH); //turn off FPV
  digitalWrite(LED, LOW); //turn LED off
  digitalWrite(uMCA_PWR, HIGH); //turn off uMCA

  //DDRB &= ~((1 << uMCA_IDLE) | (1 << uMCA_BUSY)); //set as inputs
  //PORTB |= ((1 << uMCA_IDLE) | (1 << uMCA_BUSY)); //turn on pullup resistors
  updateParam(); //set camera parameters from EEPROM
  Serial.println("____BOOT____");
}

void loop() {
  if (Serial.available() > 0) {
    char command = Serial.read();
    int serRead;
    switch (command) {
      case 'a':
        transmitGps = true;
        Serial.println("GPS TRANS ON");
        break;
      case 'b':
        transmitGps = false;
        Serial.println("GPS TRANS OFF");
        break;
      case 'c':
        Serial.println("GPS PWR ON");
        digitalWrite(GPS_PWR_CTRL, HIGH);
        break;
      case 'd':
        Serial.println("GPS PWR OFF");
        digitalWrite(GPS_PWR_CTRL, LOW);
        break;
      case 'e':
        Serial.println("GPS PRS ON");
        parseGps = true;
        break;
      case 'f':
        Serial.println("GPS PRS OFF");
        parseGps = false;
        break;
      case 'x':
        Serial.println("GPS DIRECT ON");
        gpsDirect = true;
        break;
      case 'y':
        Serial.println("GPS DIRECT OFF");
        gpsDirect = false;
        break;
      case 'g':
        Serial.println("____SET_uMCA_PARAM____");
        Serial.print("SLEEP MINUTES: ");
        while (!Serial.available()) {
          //do nothing
        }
        serRead = Serial.read() - 48;
        Serial.print(serRead);
        EEPROM.write(0, serRead);
        delay(10);
        serRead = Serial.read() - 48;
        if (serRead == -49) {
          serRead = EEPROM.read(0);
          EEPROM.write(1, serRead);
          EEPROM.write(0, 0);
          Serial.println();
        } else {
          Serial.println(serRead);
          EEPROM.write(1, serRead);
        }
        Serial.print("DELAY MINUTES: ");
        while (!Serial.available()) {
          //do nothing
        }
        serRead = Serial.read() - 48;
        Serial.print(serRead);
        EEPROM.write(2, serRead);
        delay(10);
        serRead = Serial.read() - 48;
        if (serRead == -49) {
          serRead = EEPROM.read(2);
          EEPROM.write(3, serRead);
          EEPROM.write(2, 0);
          Serial.println();
        } else {
          Serial.println(serRead);
          EEPROM.write(3, serRead);
        }
        Serial.print("PICTURES: ");
        while (!Serial.available()) {
          //do nothing
        }
        serRead = Serial.read() - 48;
        Serial.print(serRead);
        EEPROM.write(4, serRead);
        delay(10);
        serRead = Serial.read() - 48;
        if (serRead == -49) {
          serRead = EEPROM.read(4);
          EEPROM.write(5, serRead);
          EEPROM.write(4, 0);
          Serial.println();
        } else {
          Serial.println(serRead);
          EEPROM.write(5, serRead);
        }
        updateParam();
        break;
      case 'i':
        Serial.println("____READ_uMCA_PARAM____");
        serRead = EEPROM.read(0);
        serRead = EEPROM.read(1) + serRead * 10;
        Serial.print("CAMERA SLEEP TIME: ");
        Serial.print(serRead);
        Serial.println(" MINUTES");
        serRead = EEPROM.read(2);
        serRead = EEPROM.read(3) + serRead * 10;
        Serial.print("PICTURE DELAY TIME: ");
        Serial.print(serRead);
        Serial.println(" MINUTES");
        serRead = EEPROM.read(4);
        serRead = EEPROM.read(5) + serRead * 10;
        Serial.print("NUMBER OF PICTURES: ");
        Serial.print(serRead);
        Serial.println(" PICTURES");
        break;
      case 'h':
        Serial.println("____COMMANDS____");
        Serial.println("a: GPS TRANS ON");
        Serial.println("b: GPS TRANS OFF");
        Serial.println("c: GPS PWR ON");
        Serial.println("d: GPS PWR OFF");
        Serial.println("e: GPS PRS ON");
        Serial.println("f: GPS PRS OFF");
        Serial.println("x: GPS DIRECT ON");
        Serial.println("y: GPS DIRECT OFF");
        Serial.println("g: SET uMCA PARAM");
        Serial.println("i: READ uMCA PARAM");
        Serial.println("j: FPV PWR ON");
        Serial.println("k: FPV PWR OFF");
        Serial.println("l: uMCA PWR ON");
        Serial.println("m: uMCA PWR OFF");
        Serial.println("z: uMCA TAKE PIC");
        break;
      case 'j':
        Serial.println("FPV ON");
        digitalWrite(FPV_PWR, LOW);
        break;
      case 'k':
        Serial.println("FPV OFF");
        digitalWrite(FPV_PWR, HIGH);
        break;
      case 'l':
        Serial.println("uMCA_ON");
        digitalWrite(uMCA_PWR, LOW);
        delay(40000);
        if (!readIdle()){
          Serial.println("DIAGNOSTIC");
          digitalWrite(SELECT, HIGH);
          delay(100);
          digitalWrite(SELECT, LOW);
          delay(1000);
          digitalWrite(TAKE_PICTURE, HIGH);
          delay(100);
          digitalWrite(TAKE_PICTURE, LOW);
        }
        Serial.println("uMCA_ON_DONE");
        break;
      case 'm':
        Serial.println("uMCA OFF");
        digitalWrite(uMCA_PWR, HIGH);
        break;
      case 'z':
        takePic();
        break;
      default:
        Serial.println("COMMAND NOT FOUND, TYPE 'h' FOR HELP");
        break;
    }
  }
  if (millis() - uMCATimer >= uMCASleep * 60000 || uMCASleepFlag) {
    uMCASleepFlag = true;
    digitalWrite(uMCA_PWR, LOW);

    if (millis() - uMCATimer >= uMCADelay * 60000) {
      uMCATimer = millis();
      uMCACurrentPic ++;
      if (uMCACurrentPic >= uMCAPics) {
        uMCASleepFlag = false;
        digitalWrite(uMCA_PWR, HIGH);
        uMCACurrentPic = 0;
      }
      else {
        takePic();
      }
    }
  }
  if (transmitGps) {
    gpsSerial.listen();
    while (gpsSerial.available() > 1) {
      char data = gpsSerial.read();
      if (gpsDirect) {
        Serial.write(data);
      } else {
        gpsBuffer[bufferIndex] = data;
        if (bufferIndex < gpsBufferSize) {
          bufferIndex ++;
        }
      }
    }
    if (millis() - gpsTimer >= gpsDelay) {
      int startPt = 0;
      for (int j = 0; j < gpsBufferSize; j ++) {
        for (int i = 0; i < startMsgLen; i ++) {
          if (gpsBuffer[j] == startMsg[i] && i == startMsgLen - 1) {
            startPt = j + 2;
            j = gpsBufferSize; //break out of both loops
          }
        }
      }
      int endPt = 0;
      for (int j = startPt + 3; j < gpsBufferSize; j ++) {
        if (gpsBuffer[j] == endMsg) {
          endPt = j;
          j = gpsBufferSize; //break out of both loops
        }
      }
      //Serial.println(endPt);
      //Serial.println(startPt);
      gpsTimer = millis();
      bufferIndex = 0;
      if (startPt != 0 && endPt != 0) {
        if (parseGps) {
          bool validLock = true;
          for (int i = startPt; i < endPt; i ++) {
            if (gpsBuffer[i] == ',' && gpsBuffer [i + 1] == ',' && gpsBuffer [i + 2] == ','  && i < startPt + 10) {
              //Serial.println(i);
              validLock = false;
            }
          }
          if (validLock) {
            Serial.print("LAT: ");
            for (int i = startPt; i < endPt && gpsBuffer[i] != 0x0A; i ++) {

              if (gpsBuffer[i] == ',' && (gpsBuffer[i + 1] == 'N' || gpsBuffer[i + 1] == 'S') && gpsBuffer[i + 2] == ',') { //fix N and S notation
                Serial.print(" ");
                Serial.println(gpsBuffer[i + 1]);
                Serial.print("LON: ");
                i = i + 3;
              }
              if (gpsBuffer[i] == ',' && (gpsBuffer[i + 1] == 'E' || gpsBuffer[i + 1] == 'W') && gpsBuffer[i + 2] == ',') { //fix E and W notation
                Serial.print(" ");
                Serial.print(gpsBuffer[i + 1]);
                i = endPt; //break from loop
              }
              if (gpsBuffer[i] != ',') { //dont print commas
                Serial.print(gpsBuffer[i]);
              }
            }
          } else {
            Serial.print("NO LOCK");
          }
        } else {
          for (int i = startPt - startMsgLen; i < endPt && gpsBuffer[i] != 0x0A; i ++) {
            Serial.print(gpsBuffer[i]);
          }
        }
        int i;
        for (i = 0; i < gpsBufferSize; i ++) {
          gpsBuffer[i] = "";
        }
        Serial.println("");
      }
    }
  }
}

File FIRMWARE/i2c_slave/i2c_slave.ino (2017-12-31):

/*#include <Wire.h>
#include <SPI.h>

#include <Adafruit_Sensor.h>
#include <Adafruit_BMP280.h>
//Arduino Pro Mini Pin Map
#define PD1 1
#define PD0 0
#define PD2 2
#define PD3 3
#define PD4 4
#define PD5 5
#define PD6 6
#define PD7 7
#define PB0 8
#define PB1 9
#define PC3 17
#define PC2 16
#define PC1 15
#define PC0 14
#define PB5 13
#define PB4 12
#define PB3 11
#define PB2 10
#define PC4 A4
#define PC5 A5
//A7 and A6 already used in Port Names directly

//AVR Port Names
#define TAKE_PICTURE PB1
#define BMP_CSB 10 //PB2
#define uMCA_IDLE PB6
#define uMCA_BUSY PB7
#define SELECT PC1
#define SCROLL_DOWN PC2
#define SCROLL_UP PC3
#define XBEE_INT PD2
#define GPS_PWR_CTRL PD3
#define PI_PWR PD4
#define FPV_PWR PD5
#define uMCA_PWR 6
#define XBEE_SLEEP PD7
#define BAL_1 PC0
#define BAL_2 A6
#define BAL_3 A7
#define LED PB0

Adafruit_BMP280 bmp(BMP_CSB);

void setup() {
  //set inputs and outputs
  pinMode(TAKE_PICTURE, OUTPUT);
  pinMode(BMP_CSB, OUTPUT);
  pinMode(uMCA_IDLE, INPUT);
  pinMode(uMCA_BUSY, INPUT);
  pinMode(BAL_1, INPUT);
  pinMode(BAL_2, INPUT);
  pinMode(BAL_3, INPUT);
  pinMode(SELECT, OUTPUT);
  pinMode(SCROLL_DOWN, OUTPUT);
  pinMode(SCROLL_UP, OUTPUT);
  pinMode(XBEE_INT, INPUT);
  pinMode(GPS_PWR_CTRL, OUTPUT);
  pinMode(PI_PWR, OUTPUT);
  pinMode(FPV_PWR, OUTPUT);
  pinMode(uMCA_PWR, OUTPUT);
  pinMode(XBEE_SLEEP, OUTPUT);
  pinMode(LED, OUTPUT);
  //turn all load switches off and xbee off
  digitalWrite(PI_PWR, LOW);
  digitalWrite(FPV_PWR, LOW);
  digitalWrite(uMCA_PWR, LOW);
  digitalWrite(XBEE_SLEEP, HIGH);
  //start i2c interface
  Wire.begin(0X60);
  Wire.onRequest(transmit);
  Wire.onReceive(receive);
  //start serial interface
  Serial.begin(9600);
  //start spi interface
  /*if (!bmp.begin()) {
    Serial.println(F("Could not find a valid BMP280 sensor, check wiring!"));
    while (1);
  }*/
}
/*
int c[] = { -1, -1, -1}; //command, parameter 1, parameter 2

void loop() {
    digitalWrite(uMCA_PWR, LOW); //turn uMCA on
  if (Serial.available()) {
    char c = Serial.read();
    if (c == 'm') { //menu
      Serial.println("menu");
      digitalWrite(SELECT, LOW);
      delay(100);
      digitalWrite(SELECT, HIGH);
    } else if (c == 'u') { //up
      Serial.println("up");
      digitalWrite(SCROLL_UP, LOW);
      delay(100);
      digitalWrite(SCROLL_UP, HIGH);
    } else if (c == 'd') { //down
      Serial.println("down");
      digitalWrite(SCROLL_DOWN, LOW);
      delay(100);
      digitalWrite(A2, HIGH);
    } else if (c == 'p') { //picture
      Serial.println("picture");
      digitalWrite(TAKE_PICTURE, LOW);
      delay(100);
      digitalWrite(TAKE_PICTURE, HIGH);
    }
  }
  delay(1000);
  int alt = bmp.readAltitude(1013.25);
  Serial.println(alt);
}

int output; //holds i2c transmit message

void receive() {
  digitalWrite(LED, !digitalRead(LED));
  int data = Wire.read();
  if (c[0] == -1) {
    c[0] = data;
  } else if (c[1] == -1) {
    c[1] = data;
  } else if (c[2] == -1) {
    c[2] = data;
  }
  Serial.println(c[0]);
  Serial.println(c[1]);
  Serial.println(c[2]);
  switch (c[0]) {
    case 1: //readAlt
      output = bmp.readAltitude(1013.25);
      c[0] = -1; c[1] = -1; c[2] = -1;
      break;
    case 101: //readCell
      output = analogRead("CELL_" + c[1]);
      c[0] = -1; c[1] = -1; c[2] = -1;
      break;
    case 102: //takePic
      digitalWrite(TAKE_PICTURE, LOW);
      delay(100);
      digitalWrite(TAKE_PICTURE, HIGH);
      c[0] = -1; c[1] = -1; c[2] = -1;
      break;
    case 201: //setGPIO
      if (c[1] != 999 && c[2] != 999) {
        digitalWrite(c[1], c[2]);
        c[0] = -1; c[1] = -1; c[2] = -1;
      }
      break;
  }
}
void transmit() {
  Wire.write(output);
}
*/
#include "TinyGPS++.h"

// A sample NMEA stream.
const char *gpsStream =
  "$GPRMC,045103.000,A,3014.1984,N,09749.2872,W,0.67,161.46,030913,,,A*7C\r\n"
  "$GPGGA,045104.000,3014.1985,N,09749.2873,W,1,09,1.2,211.6,M,-22.5,M,,0000*62\r\n"
  "$GPRMC,045200.000,A,3014.3820,N,09748.9514,W,36.88,65.02,030913,,,A*77\r\n"
  "$GPGGA,045201.000,3014.3864,N,09748.9411,W,1,10,1.2,200.8,M,-22.5,M,,0000*6C\r\n"
  "$GPRMC,045251.000,A,3014.4275,N,09749.0626,W,0.51,217.94,030913,,,A*7D\r\n"
  "$GPGGA,045252.000,3014.4273,N,09749.0628,W,1,09,1.3,206.9,M,-22.5,M,,0000*6F\r\n";

// The TinyGPS++ object
TinyGPSPlus gps;

void setup()
{
  Serial.begin(115200);

  Serial.println(F("BasicExample.ino"));
  Serial.println(F("Basic demonstration of TinyGPS++ (no device needed)"));
  Serial.print(F("Testing TinyGPS++ library v. ")); Serial.println(TinyGPSPlus::libraryVersion());
  Serial.println(F("by Mikal Hart"));
  Serial.println();

  while (*gpsStream)
    if (gps.encode(*gpsStream++))
      displayInfo();

  Serial.println();
  Serial.println(F("Done."));
}

void loop()
{
}

void displayInfo()
{
  Serial.print(F("Location: ")); 
  if (gps.location.isValid())
  {
    Serial.print(gps.location.lat(), 6);
    Serial.print(F(","));
    Serial.print(gps.location.lng(), 6);
  }
  else
  {
    Serial.print(F("INVALID"));
  }

  Serial.print(F("  Date/Time: "));
  if (gps.date.isValid())
  {
    Serial.print(gps.date.month());
    Serial.print(F("/"));
    Serial.print(gps.date.day());
    Serial.print(F("/"));
    Serial.print(gps.date.year());
  }
  else
  {
    Serial.print(F("INVALID"));
  }

  Serial.print(F(" "));
  if (gps.time.isValid())
  {
    if (gps.time.hour() < 10) Serial.print(F("0"));
    Serial.print(gps.time.hour());
    Serial.print(F(":"));
    if (gps.time.minute() < 10) Serial.print(F("0"));
    Serial.print(gps.time.minute());
    Serial.print(F(":"));
    if (gps.time.second() < 10) Serial.print(F("0"));
    Serial.print(gps.time.second());
    Serial.print(F("."));
    if (gps.time.centisecond() < 10) Serial.print(F("0"));
    Serial.print(gps.time.centisecond());
  }
  else
  {
    Serial.print(F("INVALID"));
  }

  Serial.println();
}
